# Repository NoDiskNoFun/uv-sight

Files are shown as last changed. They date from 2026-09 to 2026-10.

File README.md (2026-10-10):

# UV-Sight

Automatic UV illumination, cant indicator and shot counter for a compound bow hunting sight, with a companion web app.

> **Disclaimer: AI-generated project**
>
> The firmware, the web app, this README and the hardware design (part selection and wiring) were created with **Claude**, an AI assistant by Anthropic, in a conversation with the project owner.
>
> | | |
> |---|---|
> | Model | Claude Opus 5.5 (Anthropic) |
> | Interface | claude.ai, chat with code execution and web search |
> | Period | 23 September 2026, finished on 25 September 2026; reviewed and extended on 30 September 2026 |
> | Human role | Requirements and feature decisions, choice and purchase of parts, soldering and assembly, compiling and flashing, testing on the real bow, bug reports |
> | AI role | Part selection and wiring, all firmware and app code, protocol design, research of datasheets and pinouts, documentation |
> | Testing by the AI | Syntax and type checks of the firmware against mock libraries, JSON validity checks, and an end-to-end test of the app in Chromium against the firmware running natively with mocked IMU, flash and Bluetooth. The AI never ran the code on real hardware. |
> | Firmware / protocol / app | Firmware 5.8, protocol 16, app 5.11 |
>
> Several values in this project are estimates or were only checked in the field by the owner (runtimes, thresholds, shot detection). Treat them as starting points, not as guarantees. LiPo batteries can be dangerous if handled wrongly. Build and use this at your own risk.

---

## Contents

1. [Features](#features)
2. [Hardware](#hardware)
3. [Wiring](#wiring)
4. [Assembly and mounting](#assembly-and-mounting)
5. [Firmware: build and flash](#firmware-build-and-flash)
6. [Operation](#operation)
7. [Battery and charging](#battery-and-charging)
8. [Bluetooth commands](#bluetooth-commands)
9. [Settings reference](#settings-reference)
10. [Compile-time constants](#compile-time-constants)
11. [Web app](#web-app)
12. [JSON protocol (version 4)](#json-protocol-version-4)
13. [Troubleshooting](#troubleshooting)
14. [Known limitations](#known-limitations)

---

## Features

- **Automatic illumination:** The UV LED lights the sight's fluorescent fibre when it is dark and the bow is in use. Brightness is set in percent, either fixed or fading in with the dusk. It is held steady over the whole battery discharge via PWM.
- **Motion-based power management:** When the bow lies still, LED, light sensor and Bluetooth switch off, the accelerometer drops to 12.5 Hz and the board sleeps until the IMU reports motion on its interrupt line. Picking the bow up wakes it at once.
- **Cant indicator:** The LED blinks when the bow is canted sideways, faster the more it is tilted, or inverted: faster the closer to level. Aiming up or down does not count. Modes: off, auto (during a session) and on (always).
- **Shot counter:** Detects every shot through the impact on the riser (IMU tap detection via hardware interrupt). Shots are grouped into ends and training sessions.
- **Scoring:** Enter the scores of each end (0–10, X, M). Each end is checked against the counted shots. Sessions and their ends are stored on the board's 2 MB flash (room for about 32,000 records).
- **Battery:** USB-C charging at a fixed 50 mA, charge status, battery percentage and a deep-discharge cutoff for the LED.
- **Bluetooth:** Everything can be read and configured over Bluetooth LE (Nordic UART Service), either with a serial terminal app or with the included web app.
- **Web app (PWA):** Status, training keypad, history with chart, CSV export, backup and import, settings with guided calibration, automatic sync of sessions in both directions. Works offline once installed.
- **Aiming range (optional):** With the distance set per end, the sight learns which aiming angle belongs to which distance and can warn when the aim does not fit the distance. Several arrow/bow setups can be kept.
- **Update mode:** Reboot into the UF2 bootloader from the app, no double click on the reset button needed.

---

## Hardware

### Bill of materials

| # | Part | Type / value | Qty | Purpose |
|---|---|---|---|---|
| 1 | Microcontroller | Seeed Studio XIAO nRF52840 **Sense** | 1 | Control, Bluetooth, built-in LiPo charger (BQ25101), USB-C, 6-axis IMU (LSM6DS3TR-C) |
| 2 | LiPo battery | 3.7 V, 85 mAh, about 4 × 12 × 25 mm, with protection circuit | 1 | Power supply |
| 3 | UV LED | 5 mm, 390–405 nm (the owner reused the LED of the sight's original light, forward voltage measured 2.873 V at about 1 mA) | 1 | Lights the sight fibre, cant indicator |
| 4 | Resistor | 68 Ω, 1/4 W | 1 | LED current limit (about 16 mA peak at 4.2 V) |
| 5 | NPN transistor | BC547 (or BC337) | 1 | Switches the LED from the battery |
| 6 | Resistor | 2.2 kΩ, 1/4 W | 1 | Transistor base resistor |
| 7 | Photoresistor (LDR) | GL5528, 5 mm | 1 | Ambient light sensor |
| 8 | Resistor | 10 kΩ, 1/4 W | 1 | Voltage divider for the LDR |
| 9 | Wire | Thin flexible silicone wire, 2 cores, about 15–20 cm | 1 | Housing to LED in the sight |
| 10 | Heat shrink | Assorted sizes | – | Insulation, strain relief |
| 11 | Housing | Rigid, screwed to the riser | 1 | See [assembly](#assembly-and-mounting) |

No separate battery voltage divider, charger module or switch is needed: the XIAO board has a battery divider, charger and USB-C on board. Power management is done entirely in software.

### Why a transistor for the LED

A GPIO pin only delivers the regulated 3.3 V of the board. A UV LED needs about 3.0–3.4 V, which leaves nearly nothing for current regulation. The LED is therefore powered directly from the battery (3.4–4.2 V) and the GPIO only switches the transistor.

### Battery notes

- The battery used here has **three wires**. The third one is a temperature sensor (NTC). The XIAO has no pad for it: **cut it short and insulate it**, only plus and minus are connected.
- Use a cell with a built-in protection circuit. It is the last line of defence against deep discharge.

---

## Wiring

### Pin assignment

| Function | XIAO pin | nRF52840 | Notes |
|---|---|---|---|
| UV LED (PWM, via transistor) | D6 | P1.11 | Base of BC547 via 2.2 kΩ |
| LDR supply | D2 | P0.28 | Only HIGH during a measurement (saves power) |
| LDR measurement | D0 / A0 | P0.02 | Midpoint of the LDR divider |
| Battery voltage | internal | P0.31 | On-board divider 1 MΩ / 510 kΩ |
| Battery measurement enable | internal | P0.14 | Kept LOW permanently (must not be HIGH while charging) |
| Charge current select | internal | P0.13 | High-impedance input = 50 mA (set in code) |
| Charge status | internal | P0.17 | LOW = charging (board charge LED) |
| IMU interrupt INT1 | internal | P0.11 | Shot detection |
| IMU power | internal | P1.08 | Switched on by the firmware |

D1, D3–D5 and D7–D10 remain free.

### UV LED

```
BAT+ ---[68 Ω]--- LED anode (+, long leg) --- LED cathode (-, short leg) --- collector (C)
                                                                             BC547
D6 -----[2.2 kΩ]------------------------------------------------------------ base (B)

GND ------------------------------------------------------------------------ emitter (E)
```

BC547 pinout, flat side facing you, legs down: **C – B – E** from left to right. Check against the datasheet of your part.

### Light sensor

```
D2 ---[LDR GL5528]---+---[10 kΩ]--- GND
                     |
                     A0
```

The LDR has no polarity. Bright light means a high reading, darkness a low reading.

### Battery

```
Battery (+) --- BAT+ pad (bottom of the XIAO)
Battery (-) --- BAT- pad
Battery NTC (3rd wire) --- not connected, insulated
```

### Overview

```
                 +--------------------------------------+
   USB-C ------> |  XIAO nRF52840 Sense                 |
                 |   (charger, IMU, Bluetooth on board) |
                 |                                      |
   LiPo 85 mAh --| BAT+ / BAT-                          |
                 |                                      |
                 | D6 ---[2.2k]--- BC547 --- UV LED ----+---- to the sight (2-core wire)
                 | D2 ---[LDR]---+                      |
                 | A0 -----------+---[10k]--- GND       |
                 +--------------------------------------+
```

---

## Assembly and mounting

- **Mount the housing rigidly.** Shot detection relies on the impact travelling through the riser. Screw the housing on, ideally to an existing accessory thread. Foam double-sided tape and magnets dampen the impact and cause missed shots. Thin structural acrylic tape without a foam core is the fallback if screwing is impossible.
- **Orientation does not matter.** All three IMU axes are evaluated for shots, and the cant indicator is calibrated in place.
- **The LED sits in the sight,** the electronics in the housing, connected by thin silicone wire with strain relief. Mark the LED polarity before desoldering an original light.
- **Place the LDR so that no UV light from the sight falls on it,** otherwise the light could switch itself off.
- **Keep the transistor and the 68 Ω resistor in the housing,** not in the sight.

---

## Firmware: build and flash

### Setup (Arduino IDE)

1. Add this boards manager URL in the preferences:
   `https://files.seeedstudio.com/arduino/package_seeeduino_boards_index.json`
2. Install the board package **"Seeed nRF52 Boards"** (not the "mbed-enabled" variant).
3. Select the board **"Seeed XIAO nRF52840 Sense"**.
4. Install the library **"Seeed Arduino LSM6DS3"** via the library manager. Bluefruit and LittleFS are part of the board package.

### Setup (arduino-cli)

```sh
arduino-cli config add board_manager.additional_urls \
  https://files.seeedstudio.com/arduino/package_seeeduino_boards_index.json
arduino-cli core update-index
arduino-cli core install Seeeduino:nrf52
arduino-cli lib install "Seeed Arduino LSM6DS3"

arduino-cli compile --fqbn Seeeduino:nrf52:xiaonRF52840Sense path/to/uv_visier/
arduino-cli upload  --fqbn Seeeduino:nrf52:xiaonRF52840Sense -p /dev/ttyACM0 path/to/uv_visier/
```

The sketch file must have the same name as its folder, for example `uv_visier/uv_visier.ino`.

### Update mode (UF2)

Instead of double-clicking the reset button you can reboot the board into its UF2 bootloader:

- in the app: *Settings → Firmware and app → Update mode*, or
- in a terminal: send `dfu`.

The USB cable must be connected, otherwise the command is refused (the board would sit in the bootloader and drain the battery). The board appears as a USB drive. Copy a `.uf2` firmware onto it, or upload with the Arduino tools.

### What is stored in flash

| File | Where | Content | Saved |
|---|---|---|---|
| `/uvcfg.bin` | internal | Settings | With `save` |
| `/shotstate.bin` | internal | Shot counter on/off, log epoch, last session number | Automatically |
| `/level.bin` | internal | Cant indicator mode, calibration, LED switch, signals | Automatically |
| `/setups.bin` | internal | Arrow/bow setups | Automatically |
| `/sightname.txt` | internal | Name of this sight (`name <text>`) | Automatically |
| `/shotmodel.bin` | internal | Shot matching model per setup and its on/off switch | Automatically |
| `/bathist.bin` | internal | Battery history for the runtime estimate | Automatically |
| session log | external 2 MB QSPI flash | Sessions and ends as 64-byte records with CRC, ring buffer | Automatically |
| `/shots.old` | internal | Backup of the log format of firmware 1.2 to 2.1 after the migration | Once |

When a firmware update changes the layout of an internal file, that file starts over with defaults. The session log on the external flash keeps its format. Export a backup from the app before updating anyway.

---

## Operation

### Active and idle

- **Active:** The bow was moved within the timeout (default 5 min). LED logic, light sensor and Bluetooth run.
- **Idle:** The bow lies still. Everything is off. The IMU's interrupt line wakes the board when the bow moves; without motion it only wakes every 5 s for housekeeping. A Bluetooth connection is dropped when the board goes idle; a connection alone does not keep it awake. USB power or an `awake` hold from the app keep Bluetooth reachable without movement.
- A running session survives idle phases. It is only ended by `session_end` minutes without a shot, by `shots stop`, or by a restart of the board.

### Illumination

- Every 2 s the light sensor is read (0 = dark, 4095 = bright).
- `confirm` readings in a row are needed to switch. Right after picking up the bow the decision is immediate.
- **Brightness in percent** on a perceptual scale: 50 % looks about half as bright as 100 %. 100 % is 15 mA average, the former default of 5 mA is 61 %.
- **Fixed** (`bright_mode 0`): below `dark_on` the LED switches on with `bright`, above `dark_off` it switches off. The gap prevents flicker.
- **Auto** (`bright_mode 1`): getting darker, the LED comes on at `dark_off` with `bright_min` and gets brighter until it reaches `bright` at `dark_on`; below that it stays at `bright`. Getting brighter, it dims the same way and goes off above `dark_off`. The blend follows the light sensor logarithmically and glides over `fade` seconds instead of jumping.
- The brightness is kept steady by PWM (12 bit) as the battery voltage drops.
- Test modes: `mode on` (always on), `mode off` (always off), `mode auto` (normal). The mode is not saved.

### Cant indicator

| | level | canted |
|---|---|---|
| bright | LED off | LED blinks |
| dark | LED on | LED blinks |

- Blinking uses `bright` minus `tilt_offset` percentage points (0 = same brightness), independent of the current auto brightness.
- **Style normal:** just outside the tolerance `blink_min` (1 Hz), from `tilt_full` (10°) on `blink_max` (8 Hz), in between the rate rises linearly.
- **Style inverted** (`level style inverted`): just outside the tolerance `blink_max`, from `tilt_full` on `blink_min`, so fast blinking means you are close to level. Within the tolerance the LED behaves as in normal style (on when dark, off when bright).
- The cant reading is smoothed over `tilt_smooth` against hand tremor. Leaving the tolerance switches at `level_tol`, returning at 70 % of it, so the edge does not flicker.
- A new rate takes effect at the start of the next blink cycle.
- Only sideways cant counts. Aiming up or down is ignored thanks to the two-step calibration.
- After a shot the indicator pauses for `lockout` (default 1.5 s).

| Mode | Command | Behaviour |
|---|---|---|
| Off | `level off` | No blinking |
| Auto | `level auto` | Only during a running session (needs `shots on`) |
| On | `level on` | Always while the bow is active |

**Calibration (once, saved immediately):**

1. Put the bow in a stand, level it with the bubble and aim horizontally. Send `level cal`.
2. Keep the bow level, but aim clearly up or down, at least 20°. Send `level cal2`.

Each step waits 3 s, then measures for about 0.6 s. If the two positions differ by less than 15°, step 2 has to be repeated.

### Shot counter, sessions and ends

- Turn the counter on with `shots on` (saved immediately).
- **Session start:** automatically with the first detected shot, or manually with `shots start`.
- **Shot detection:** The IMU reports impacts above `tap_ths` via interrupt. After a shot further impacts are ignored for `lockout`. Setting the bow down at the end often counts as a shot; this is handled below.
- **Ends:** Each `score` line closes an end and is compared with the shots counted since the last entry.
  - Match: the end is saved.
  - Mismatch: the device asks `save anyway? (yes/no/split)`. `yes` saves your values and your arrow count wins over the sensor count. `split` (offered when fewer values than shots were entered) saves the values as one end and keeps the remaining shots for the next end. `no` discards the input and the end stays open. Any command that changes the session or a setting also discards the input; commands that only read (`status`, `log …`, `level`, …) and the sync commands of the app leave the question open.
  - `score skip` closes an end without scores: it is stored as invalid, the sensor's arrow count is used, all arrows count 0 points and are left out of the average.
- **Scores:** `0`–`10` and `x` (inner ten: 10 points, counted separately). Several values per line, for example `score x 10 9 9 8 7`. If one value is invalid, the whole line is rejected. The app shows 0 as M (miss).
- **Session end:** automatically after `session_end` minutes (default 60) without a shot, or with `shots stop`. An open last end with exactly 1 shot is ignored (bow set down); with more shots it is stored as invalid. Sessions without any end are discarded.
- **Stored per session:** ends, shots, scored arrows, average, X count, duration in minutes, invalid ends and arrows, flags (corrected by hand, ended by hand). There is no clock on the board; the app derives the date.
- The log lives on the external flash and holds about 32,000 records; the oldest are overwritten when it is full. The app can delete single sessions or the whole log on the sight.

---

## Shot matching

With the shot counter running, the sight also records how the bow moved at each release and tells the app, per shot, where it expects the arrow relative to the end's mean: the height from the aiming angle, the sideways position from the bow's rotation in the last 30 ms before the impact (gyroscope, read from the IMU FIFO, shot mode only). The app matches these predictions to the arrow positions it sees on the photo and reports the sure pairs back (`shot teach`). From them, each setup learns its own factors and the remaining spread, so the predictions and the app's confidence improve with every end. Everything is stored per setup in `/shotmodel.bin`; `shot model` shows the state, `shot reset` starts over, `shot off` turns matching and the gyro off. The gyro adds about 0.5 mA while the bow is active.

## Battery and charging

| Item | Value |
|---|---|
| Charge current | Fixed 50 mA (about 0.6 C for 85 mAh), about 2 h for a full charge |
| Charge termination | 4.2 V (charger chip) |
| LED cutoff | `cutoff`, default 3.40 V; released again at cutoff + 0.25 V |
| Percentage | 0 % = `cutoff`, 100 % = 4.2 V, following a typical LiPo curve |
| Charge status | `charging`, `full` (USB connected, done), `no USB` |

- While charging the voltage reads higher than at rest, so the percentage is optimistic. After charging a full cell settles to about 4.10–4.15 V.
- The ADC uses a 40 µs acquisition time because the on-board battery divider has a very high impedance. With the default 3 µs the voltage read about 0.1 V too low.
- The microcontroller keeps running below the cutoff; the battery's own protection circuit disconnects at roughly 2.5–3.0 V. The cutoff is what protects the cell from the LED.

### Runtime estimates

These are estimates, not measurements.

| Mode | Current (approx.) | Runtime with 85 mAh |
|---|---|---|
| Idle (bow lies still) | 0.04–0.08 mA | several weeks up to about 2 months |
| Active at night, LED at 61 % (5 mA) | about 6 mA | about 14 h |
| Active in daylight, training, no LED | 0.5–1 mA | several days |

Measurements taken with a USB power meter are not meaningful for battery runtime: with USB connected, the USB interface of the chip is active and the LED draws from the battery, not from USB.

---

## Bluetooth commands

Connect with any Nordic UART terminal (for example the Android app "Serial Bluetooth Terminal", line ending LF or CR+LF), with `ble-serial` on Linux, or with the web app. The board advertises as **UV-Sight** only while it is active.

| Command | Effect | Saved |
|---|---|---|
| `help` or `h` | List of commands | – |
| `status` or `?` | Current readings | – |
| `get` or `config` | All settings with range | – |
| `set <name> <value>` | Change a setting, active immediately | Only with `save` |
| `save` | Save settings to flash | Yes |
| `defaults` | Load default settings | Only with `save` |
| `live on` / `live off` | Status every 2 s | No |
| `mode auto` / `on` / `off` | LED test mode | No |
| `shots` | Counter status and running session | – |
| `shots on` / `shots off` | Shot counter on/off (off only without a running session) | Immediately |
| `shots start` / `shots stop` | Start / end a session manually | Slot on end |
| `score 9 x 7 0` | Score an end | With the session |
| `score skip` | Close the end without scores (invalid) | With the session |
| `yes` / `no` | Answer a mismatch question | – |
| `log` | Stored sessions, 1 = newest | – |
| `level` | Cant indicator status | – |
| `level off` / `auto` / `on` | Cant indicator mode | Immediately |
| `level style normal` / `inverted` | Blink faster when tilted / when close to level | Immediately |
| `level cal` / `level cal2` | Calibration step 1 / 2 | After step 2 |
| `level signal on` / `off` | Blink when canted (measuring continues) | Immediately |
| `angle off` / `auto` / `on` | Measure the aiming angle at every shot | Immediately |
| `dist <m>` | Distance of the running session (0 = unknown); `score … @50` also sets it | With the session |
| `range`, `range signal on` / `off` | Learned distances and arrow speed; warning when the aim does not fit | Immediately |
| `setup`, `setup use` / `new` / `name` / `del` | Arrow/bow setups, each learns its own speed | Immediately |
| `log all`, `log since <n>`, `log ends <e> <id>`, `log info`, `log test` | Whole log, records after #n, ends of a session, flash status, flash self-test | – |
| `log put …`, `log putend …` | Write a session / end from a backup (used by the app) | Yes |
| `log del <e> <id>`, `log clear confirm` | Delete one session / all sessions on the sight | Yes |
| `bat`, `bat reset` | Runtime estimate and measured current draw; clear the battery history | – / Yes |
| `time <unix> [tz]` | Set the clock (the app does this on every connect) | Until reboot |
| `awake <s>` | Stay reachable without movement, max 900 s | No |
| `app on` / `app off` | JSON output for the app / human-readable output | No (off on disconnect) |
| `name [text]`, `name -` | Name this sight (max. 16 characters); it appears in the app and behind "UV-Sight" in the Bluetooth name. `-` removes the name. The app also receives a fixed chip id, so two sights are told apart even without a name | Yes |
| `shot list [m]` | Shots of the open end, one line each (`shotsStart`, `shotItem`…, `shotsEnd`): time, aiming angle, hold spread and duration, sinking before release, cant, bow rotation at release and the model's predicted position. The same lines follow every closed end | – |
| `shot trace [last] <i>` | Aim trace of one shot: angle and cant over the 1.9 s before the release | – |
| `shot teach <end> <i>:<dx>:<dy> …` | Confirmed arrow positions (mm from the group's mean) for shots of the last closed end: the model learns from them | Yes |
| `shot model`, `shot reset [id]`, `shot on`/`shot off` | Shot matching model of the active setup: state, reset, switch (off also turns the gyro off) | Yes |
| `dfu` | Reboot into update mode (USB needed) | – |

Range is about 10 m at the default `tx_power` of 0 dBm; +8 dBm roughly doubles it. A cheap USB adapter without antenna, a metal PC case or a nearby USB 3 port can reduce the range a lot. Anyone within range can connect; there is no PIN.

---

## Settings reference

Change with `set <name> <value>`, keep with `save`. Out-of-range values are rejected. Settings saved by firmware before 1.8 in mA (`ma`, `tilt_ma`) are converted to percent automatically on the first start.

| Name | Meaning | Unit | Default | Min | Max |
|---|---|---|---|---|---|
| `dark_on` | Fixed: light on below. Auto: full brightness from here down | 0–4095 | 900 | 0 | 4095 |
| `dark_off` | Fixed: light off above. Auto: light starts here with `bright_min` | 0–4095 | 1200 | 0 | 4095 |
| `confirm` | Consecutive readings (2 s each) before switching | count | 2 | 1 | 10 |
| `bright_mode` | 0 = fixed, 1 = auto (fades with the light sensor) | – | 0 | 0 | 1 |
| `bright` | Brightness (fixed), or at `dark_on` and darker (auto) | % | 61 | 1 | 100 |
| `bright_min` | Auto: brightness at `dark_off`, where the light starts | % | 25 | 1 | 100 |
| `tilt_offset` | Cant blinking: percentage points below `bright` | % | 32 | 0 | 99 |
| `fade` | Auto: time to follow a change in darkness, 0 = instant | s | 5 | 0 | 30 |
| `tilt_full` | Cant at which the blink rate reaches its end value | degrees | 10.0 | 1 | 30 |
| `blink_min` | Slow blink rate (normal: just outside the tolerance) | Hz | 1.0 | 0.5 | 12 |
| `blink_max` | Fast blink rate (normal: from `tilt_full` on); above ~10 Hz it looks steady | Hz | 8.0 | 0.5 | 12 |
| `tilt_smooth` | Smoothing of the cant reading against hand tremor | ms | 400 | 50 | 2000 |
| `session_end` | Minutes without a shot until the session ends | min | 60 | 5 | 480 |
| `vf` | Forward voltage of the UV LED (for the brightness control) | V | 3.00 | 2.50 | 3.60 |
| `cutoff` | Battery cutoff for the LED, equals 0 % | V | 3.40 | 3.00 | 3.70 |
| `level_tol` | Cant tolerance | degrees | 1.0 | 0.2 | 10 |
| `tap_ths` | Shot threshold | × 0.25 g | 20 (5 g) | 1 | 31 |
| `ths` | Wake-up motion threshold | × 125 mg | 1 | 1 | 63 |
| `lockout` | After a shot: no counting, cant indicator paused | ms | 1500 | 200 | 5000 |
| `timeout` | Time without movement until idle | s | 300 | 10 | 3600 |
| `report` | Automatic status while connected, 0 = off. A status the app asks for restarts this timer, so polling and reports do not double up | s | 10 | 0 or 2 | 600 |
| `tx_power` | Bluetooth transmit power, rounded to −20, −16, −12, −8, −4, 0, 2…8 | dBm | 0 | −20 | 8 |
| `bat_mah` | Battery capacity, for the runtime estimate | mAh | 85 | 10 | 5000 |

**Calibrating the light thresholds:** at dusk send `live on`, watch the `Light=` value, set `dark_on` where the fibre no longer glows by itself and `dark_off` about 300 higher. Then `live off` and `save`.

**Calibrating the shot threshold:** every detected shot is reported. Shoot a few arrows and carry the bow around. Lower `tap_ths` if shots are missed, raise it if carrying counts as a shot. Then `save`.

---

## Compile-time constants

`UV_HAS_LED` (default 2): whether the UV LED stage (BC547, resistors, LED, light sensor) is fitted. 0 = no, for a sight on a bow without a pin, e.g. a hunting bow, that only counts shots and measures angles; 1 = yes; 2 = find out at boot. The check charges the LED pin and lets it float for a moment: with the transistor and its base resistor fitted the pin falls to the base-emitter voltage, without them it stays high. Without the LED stage the light settings default to off, the light sensor is not read, `mode on`, `level signal on` and `range signal on` are refused, and the app hides all light options (the `hello` message carries `"led":false`). Set it on the command line with `--build-property compiler.cpp.extra_flags=-DUV_HAS_LED=0`.

These are set at the top of the sketch and need a rebuild.

| Constant | Value | Meaning |
|---|---|---|
| `BRIGHT_MAX_MA` | 15 mA | LED current at 100 % |
| `BRIGHT_GAMMA` | 2.2 | Perceptual curve from percent to current |
| `PWM_BITS` | 12 | PWM resolution for fine steps at low brightness |
| `MAX_SCORES_LINE` | 40 | Maximum values per `score` line |
| `TILT_HYST_FRAC` | 0.3 | Hysteresis at the tolerance edge as a share of `level_tol` |
| `CAL_MIN_ANGLE_DEG` | 15° | Minimum angle between the calibration steps |
| `CAL_COUNTDOWN_MS` | 3000 ms | Wait before a calibration measurement |
| `SENSOR_INTERVAL_MS` | 2000 ms | Light and battery reading interval |
| `ACTIVE_POLL_MS` / `LEVEL_LOOP_MS` | 250 / 30 ms | Loop interval active / with cant indicator or aiming angle |
| `IDLE_WAKE_MAX_MS` / `IDLE_POLL_MS` | 5000 / 500 ms | Idle: longest sleep between housekeeping passes (the IMU interrupt ends it earlier) / poll interval if the board package has no INT1 pin |
| `TWIM_ANOMALY_89` | 1 | nRF52840 erratum 89 workaround (I2C peripheral off between loop passes): 0 = never, 1 = automatic (the firmware asks the Nordic MDK whether the chip revision is affected; only Engineering A is), 2 = always. `bat` shows whether it is active |
| `ADV_FAST_INTERVAL` / `ADV_SLOW_INTERVAL` | 100 ms / ~1 s | Advertising for the first 10 s / afterwards |
| `CONN_INT_MIN` / `CONN_INT_MAX` | 200 / 400 ms | Requested connection interval |
| `BLE_NAME` | `UV-Sight` | Bluetooth name |

---

## Web app

### Files

All six files belong in one folder:

```
index.html
sw.js
manifest.webmanifest
icon-192.png
icon-512.png
icon-maskable-512.png
```

The main file must be named exactly `index.html`.

### Hosting and installing

Web Bluetooth only works in **Chrome** and only on pages loaded via **https** or **localhost**. Opening the file directly from storage does not work.

- **Online Version**: [https://nodisknofun.github.io/uv-sight/](https://nodisknofun.github.io/uv-sight/)
- **Local server on the phone:** serve the folder with a local web server app and open `http://localhost:8080/`.
- **GitHub Pages:** create a repository, upload the six files, enable *Settings → Pages* for the `main` branch. The app is then at `https://<user>.github.io/<repo>/`.
- **Own server:** any static https web server.

Open the app once completely, then install it via *Settings → Install app* or the Chrome menu. After that it starts from the home screen without internet. When the server is reachable it loads updates automatically (network first, cached copy after 2.5 s).

If the device chooser stays empty, give Chrome the permission *Nearby devices* (Android 12 and later) or *Location* (older Android).

### Tabs

- **Status:** battery ring with percentage and voltage, session, UV light with brightness and mode (fixed/auto), ambient light, cant with mode and style, charging, and runtime estimates with light and resting. Refreshes every 5 s while open.
- **Runtime estimate:** remaining capacity (battery capacity × percentage) divided by an estimated current: LED at `bright` plus about 0.6 mA for the awake board, 0.2 mA each for shot detection and the cant indicator when switched on; resting about 0.06 mA. In auto mode the estimate assumes full brightness. Set the battery capacity under *Settings → Firmware and app* (default 85 mAh, stored on the phone).
- **Training:** current end with live shot count, session statistics, keypad in target ring colours (`1 2 3 / 4 5 6 / 7 8 9 / 10 X M`, undo), save end, skip end, end session. Scoring works without a connection; Save, Skip and End reconnect automatically (up to 10 s) and keep your entries if the sight is out of range. Entries survive an app restart. Mismatch questions appear as a dialog; *Edit scores* keeps your entries for correction.
- **History:** sessions from the device are archived on the phone without duplicates, with date, chart of the average and CSV export. Removing an entry only affects the phone.
- **Dates:** the sight has no clock. The app takes the date from the phone: when a session ends while connected, from `ago` when fetched later, or from the start time it remembered while it saw the session running. Only if the app was never connected during a session and the sight restarted before the session was fetched, the list shows "Before <fetch time>".
- **Settings:** battery capacity for the estimate, shot counter, cant indicator (off/auto/on) and blink style (normal/inverted), LED test, brightness mode (fixed/auto), all settings grouped with slider, number field, description, default and range, save bar, restore defaults, guided cant calibration, update mode, install button, versions.
- **Console:** raw lines and free command input for troubleshooting.

The archive is stored in Chrome's site data. Clearing Chrome's site data deletes it; export CSV now and then as a backup.

---

## JSON protocol (version 16)

After `app on` the device sends **only JSON, one object per line**, until `app off` or disconnect. Commands stay the same text commands. Every object has a type field `t`. Lines that do not start with `{` (for example the greeting before `app on`) can be ignored.

On `app on` the device sends `hello`, the settings (`cfgStart`, `cfgItem` …, `cfgEnd`), `status`, `session`, `level`, `loginfo`, `range` and the setups (`setupsStart`, `setupItem` …, `setupsEnd`).

| Type | Fields | Sent |
|---|---|---|
| `hello` | `proto`, `fw`, `name`, `imu`, `log` | On `app on` |
| `status` | `light`, `dark`, `vbat`, `pct`, `chg` (`charging`/`full`/`no USB`), `led` (`on`/`off`/`blinking`/`warning`/`pulsing`), `duty` (0–4095), `bright` (%), `mode`, `lowbat`, `tilt` (degrees or `null`), `session`, `awake`, `rwarn`, `lastShotG`, `lastShotClip`, `end`, `endShots` | On `status`, with `live on` every 2 s, every `report` s |
| `bat` | `light`, `rest` (hours), `full` (minutes or `null`), `src` (`measured`/`estimate`), `idleMa`, `activeMa`, `ledK`, `cap` | With every status |
| `cfgStart` | `n` | Start of the settings list |
| `cfgItem` | `k`, `v`, `def`, `min`, `max`, `dec`, `zero`, `unit`, `d` | One per setting |
| `cfgEnd` | – | End of the settings list |
| `session` | `counter`, `active`; if active also `epoch`, `nextId`, `dist`, `distSrc`, `end`, `endShots`, `ends`, `invalidEnds`, `shots`, `scored`, `sum`, `x`, `avg`, `min`, `pending` | On `shots`, after every change |
| `shot` | `end`, `endShots`, `total`, `g`, `clip`, `ang`, `cant` | Every detected shot |
| `end` | `n`, `valid`, `arrows`, `dist`, `distSrc`, `setup`, `ang`, `angSd`, `angN`, `cant`, `cantMax`, `canted`, `cantN`, `stored`; valid: `sum`, `x`, `avg`; invalid: `reason` | An end was closed |
| `confirm` | `end`, `counted`, `entered`, `split` | Mismatch, answer with `yes`, `no` or `split` |
| `discarded` | `end` | Input discarded, end still open |
| `sessionEnd` | `manual`, `stored`, `epoch`, `id`, `seq` (0 if not stored), `error` | Session ended (`stored:false` for empty sessions or a flash error); a `slot` line with the details follows |
| `logStart` | `since`, `last`, `total`, `epoch` | Start of a log answer |
| `slot` | `seq`, `epoch`, `id`, `start`, `ago`, `ends`, `shots`, `scored`, `avg`, `x`, `min`, `invalidEnds`, `invalidArrows`, `mismatch`, `manual` | One per stored session |
| `endrec` | `seq`, `epoch`, `id`, `n`, `valid`, `arrows`, `skipped`, `sum`, `x`, `dist`, `auto`, `setup`, `ang`, `angSd`, `angN`, `cant`, `cantMax`, `canted`, `cantN`, `scores` | One per stored end |
| `logEnd` | `last`, `n` (records sent in this answer) | End of a log answer. The app compares `n` with what it received and asks again if a line was lost |
| `loginfo` | `ok`, `jedec`, `count`, `capacity`, `last`, `clock`, `migrated`, `error`, `initErr`, `resets` | On `log info` and `app on` |
| `range` | `setup`, `name`, `state` (`learning`/`anchor`/`ready`), `ends`, `dists`, `min`, `max`, `speed`, `kmh`, `drag`, `dist`, `distSrc`, `estimated`, `signal`, `warn`, `ok` | On `range`, after changes |
| `setupsStart` / `setupItem` / `setupsEnd` | `active`; per item `id`, `name`, `deleted`, `state`, `ends`, `kmh`, `min`, `max` | On `setup`, after changes |
| `logtest` | `step`, `ok`, `detail` | During `log test` |
| `level` | `mode` (`off`/`auto`/`on`), `style` (`normal`/`inverted`), `cal`, `angle` (`off`/`auto`/`on`), `cantSignal`, `rangeSignal` | On `level`, after changes |
| `cal` | `step`, `state` (`countdown`/`ok`/`error`), `text` | During calibration |
| `event` | `e`: `idle`, `lowbat`, `charge` (+`state`), `light` (+`dark`), `range` (+`warn`: `low`/`high`/empty, `ok`) | Device events. `range` is sent whenever the aiming-range signal changes, so an app can mirror the LED (e.g. by vibrating) |
| `ack` | `cmd`: `set` (+`k`, `v`), `save`, `live` (+`on`), `mode` (+`mode`), `dfu`, `dist`, `awake`, `time`, `batreset`, `setup` (+`ok`, `id`), `put` / `putend` (+`result`), `del` (+`result`), `clear` (+`ok`, `count`) | Confirmation of a command |
| `err` | `text` | Error |
| `msg` | `text` | Any other human-readable message |

**Session identity:** `epoch` is a random number of the log, newly created whenever the log starts empty. `id` is a running session number. `epoch` + `id` identify a session uniquely. A running session already reports the key it will get (`epoch` + `nextId`). `seq` is the write number of a record on the flash; the app remembers the newest `seq` it has and asks for `log since <seq>`. `start` is the unix time of the session start if the app had set the clock, `ago` the number of minutes since the session was saved, or `null` after a reboot of the board.

**Why short lines:** long lines (about 1,500 characters) were lost or corrupted over Bluetooth in practice. The settings are therefore sent as one short line per item. No line is longer than about 350 characters.

---

## Troubleshooting

| Problem | Cause and fix |
|---|---|
| App or terminal does not find `UV-Sight` | The board is idle. Move the bow, then search within 10 s. |
| PC finds the sight only briefly or not at all | Weak adapter: use a USB extension cable, avoid USB 3 ports, or raise `tx_power`. On Linux connect directly with `ble-serial -d <MAC> -t 15`; pairing is not needed. |
| Connection drops | After `timeout` without movement the board disconnects on purpose. Move the bow or raise `timeout`. |
| Settings tab says "Loading settings…" for long | Lines got lost. The app retries three times; move closer and tap *Try again*. |
| Protocol warning in the app | Firmware and app versions do not match. Update both. |
| Status reports keep coming after `live off` | That is the periodic `report`. Set `report 0` to switch it off. |
| Linker error about `GPIOTE_IRQHandler` | The sketch owns the GPIOTE interrupt for the IMU line. Nothing else in the sketch may call `attachInterrupt`. |
| LED switches nervously at dusk | Raise `confirm` or widen the gap between `dark_on` and `dark_off`. |
| Fibre too bright in full darkness | Lower `bright`; in auto mode it applies from `dark_on` down. |
| Shots are not counted | Check `shots` is on and the housing is screwed rigidly. Lower `tap_ths`. |
| Carrying the bow counts as a shot | Raise `tap_ths`. Setting the bow down at the end of a session is handled automatically. |
| Cant indicator never blinks | Check `level`: mode, calibration, and in auto mode a running session. |
| Cant blinks although the bubble is centred | Repeat the calibration or raise `level_tol`. |
| Battery percentage too high while charging | Normal, read it some minutes after unplugging. |
| LED stays off, "BATTERY EMPTY" | Deep-discharge protection. Charge the battery. |
| Settings lost after restart | `save` was missing, or the settings layout changed with a firmware update. |
| Compile error "does not name a type" | Arduino generates function prototypes before the first function; all types must be defined above it. Keep the order of the sketch. |
| Warning "PIN_LSM6DS3TR_C_INT1 not defined" | Board package without the interrupt pin; shot detection falls back to polling and may miss shots. |

---

## Known limitations

- **No clock:** sessions have no timestamp on the device. Dates come from the phone and are only approximate ("Before …") if the app never saw the session running and the sight restarted before it was fetched.
- **Shot detection by impact threshold:** setting the bow down hard can count as a shot. The threshold has to be tuned per bow and mounting position.
- **No Bluetooth security:** anyone in range can connect and change settings while the bow is active.
- **Cold:** below 0 °C LiPo capacity drops noticeably; runtime will be shorter than estimated.
- **Estimates:** runtimes and some thresholds are estimates and were not measured by the author of the code.
- **Web Bluetooth:** only Chrome on Android is supported; iPhone browsers do not support Web Bluetooth.
- **Erratum 89 of the chip:** the nRF52840 erratum that adds up to about 0.4 mA while the I2C peripheral stays enabled next to GPIOTE only affects the revision Engineering A, which no XIAO board carries. The firmware checks the revision at start and applies the workaround only there (`TWIM_ANOMALY_89`).

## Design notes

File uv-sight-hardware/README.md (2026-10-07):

# UV-Sight Hardware

Carrier board and 3D-printed case for **UV-Sight**: automatic UV illumination, cant indicator and shot counter for a compound bow sight, built around a Seeed Studio XIAO nRF52840 Sense.

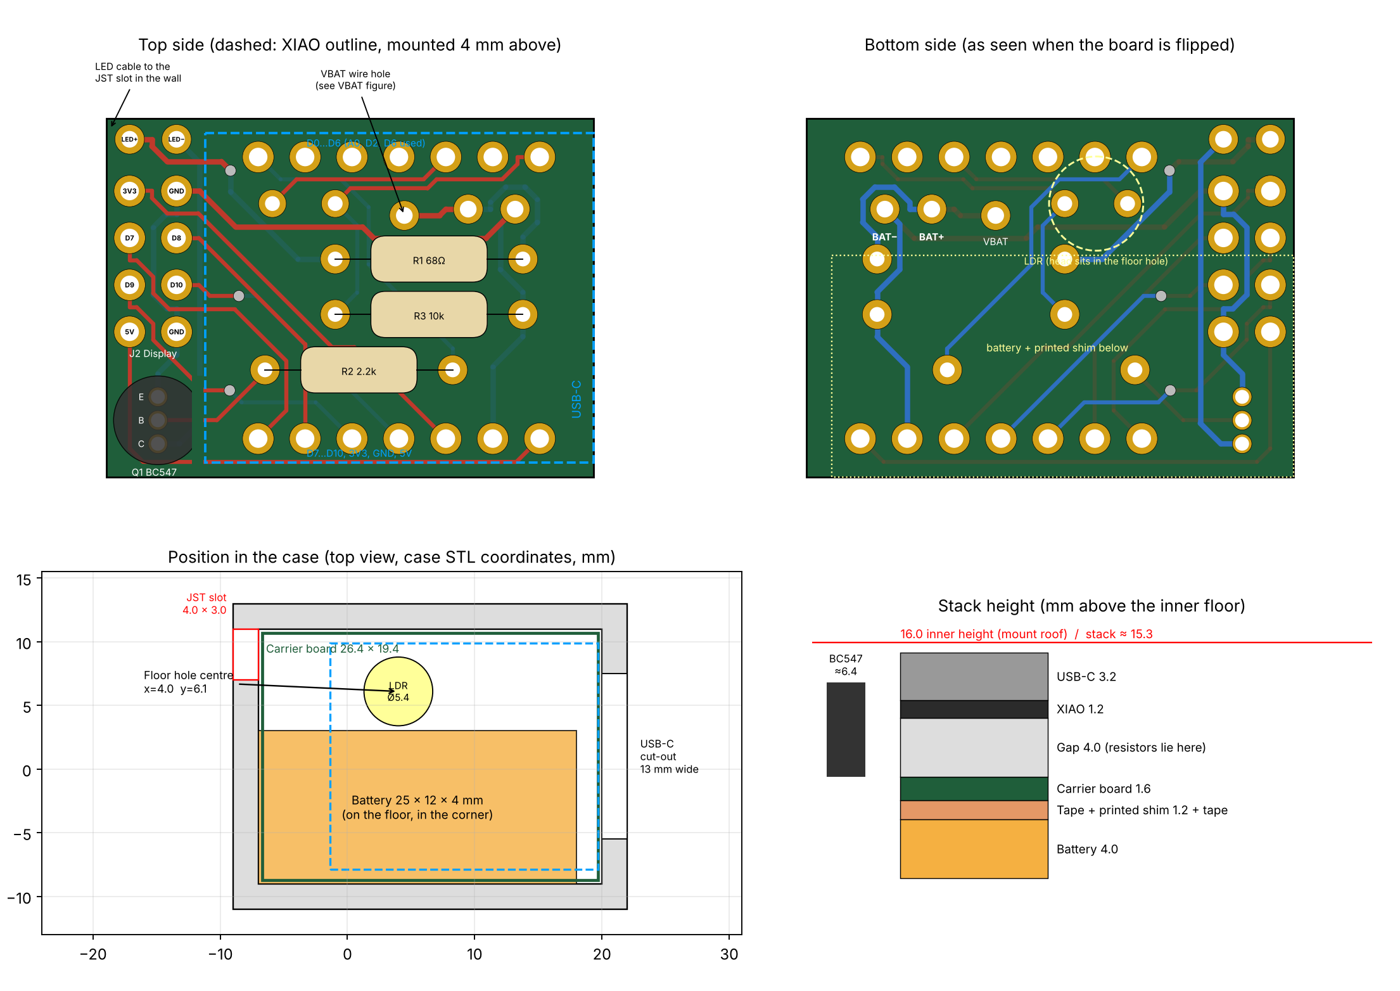
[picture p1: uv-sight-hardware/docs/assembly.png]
Assembly overview


> **AI-generated design.** The board layout, schematic, case modifications and this guide were created with Claude (Anthropic) together with the project owner. The design has been checked with KiCad's design rule check and against the 3D models, but **it has not been built and tested on real hardware yet.** Build at your own risk. LiPo batteries can be dangerous if handled wrongly.

---

## What's in this folder

| Folder / file | What it is | Do you need it? |
|---|---|---|
| `gerber/uv-sight-carrier_gerber.zip` | Manufacturing files for the board | **Yes**: upload this zip to a PCB maker |
| `3d-print/case.stl` | Case, fits the bow mount | **Yes**: print it |
| `3d-print/shim.stl` | 1.2 mm spacer between battery and board | **Yes**: print it |
| `3d-print/header-spacer.stl` | 1.5 mm strip that lifts the XIAO on its pin header | **Yes**: print it **twice** |
| `3d-print/rail-test/` | Four short test pieces to find the right rail fit for your printer | Recommended |
| `docs/` | Assembly drawing, VBAT wire drawing, schematic (PDF), mount fit | Read while building |
| `kicad/` | KiCad project (schematic and board) | Only if you want to change the design |

---

## 1. Order the board

Upload `gerber/uv-sight-carrier_gerber.zip` to any PCB maker (JLCPCB, PCBWay, Aisler and others). Use these settings:

| Setting | Value |
|---|---|
| Layers | 2 |
| Size | 26.4 × 19.4 mm |
| Thickness | **1.6 mm** (the height of the case is calculated with 1.6 mm) |
| Surface finish | HASL lead-free or ENIG |
| Colour | any |

Minimum track width 0.3 mm, minimum clearance 0.2 mm and minimum drill 0.3 mm are standard at every maker.

## 2. Print the parts

**Material: PETG** (or ASA if your printer has an enclosure). Do not use PLA. It softens at about 55 °C, for example in a car in summer, and becomes brittle in the cold.

- Use an **opaque, dark** filament. Translucent plastic lets light through the walls onto the light sensor and spoils the light reading.
- Layer height 0.12–0.16 mm, at least 5 perimeters (the 2 mm walls come out solid).
- Print the case with the open side up.

**Rail fit:** the rails on the sides of the case slide into the bow mount. Printers differ, so first print the four pieces in `3d-print/rail-test/`, **in the same material as the case**. They have 0.10, 0.15, 0.20 and 0.25 mm less material on each face of the rail. The number of notches on top of one wall tells you which is which (1 notch = 0.10 mm, 4 notches = 0.25 mm). Pick the one that slides in with a little force. `case.stl` uses **0.15 mm**. If you need another value, the case has to be regenerated with that value.

## 3. Parts list

| Ref | Part | Qty | Notes |
|---|---|---|---|
| U1 | Seeed Studio XIAO nRF52840 **Sense** | 1 | |
| – | Pin header 1×7, 2.54 mm | 2 | connects the XIAO to the carrier board |
| – | `header-spacer.stl`, printed | 2 | lift the XIAO to 4 mm above the board so the resistors fit underneath |
| R1 | Resistor 68 Ω, 1/4 W | 1 | LED current |
| R2 | Resistor 2.2 kΩ, 1/4 W | 1 | transistor base |
| R3 | Resistor 10 kΩ, 1/4 W | 1 | light sensor divider |
| Q1 | BC547 (or BC337), TO-92 | 1 | |
| R4 | Photoresistor GL5528, 5 mm, leaded | 1 | |
| J1 | LiPo 3.7 V, 85 mAh, about 4 × 12 × 25 mm, **with protection circuit** | 1 | wires soldered to J1 |
| J3 | UV LED 5 mm, 390–405 nm, on a 2-wire cable | 1 | sits in the sight |
| – | Micro-JST 1.25 mm 2-pin plug + socket with wires (PicoBlade compatible, about 4 × 3 mm) | 1 pair | LED cable through the case wall |
| – | Thin insulated wire, e.g. 30 AWG wire-wrap wire | ~2 cm | **VBAT wire** (see step 6) |
| – | Double-sided tape without foam core, e.g. 3M 467MP | – | holds battery, shim and board |
| – | Pin header 2×4 or wires (optional) | 1 | display connector J2 |

## 4. Build the board

The order matters: the XIAO covers everything below it once it is soldered in.

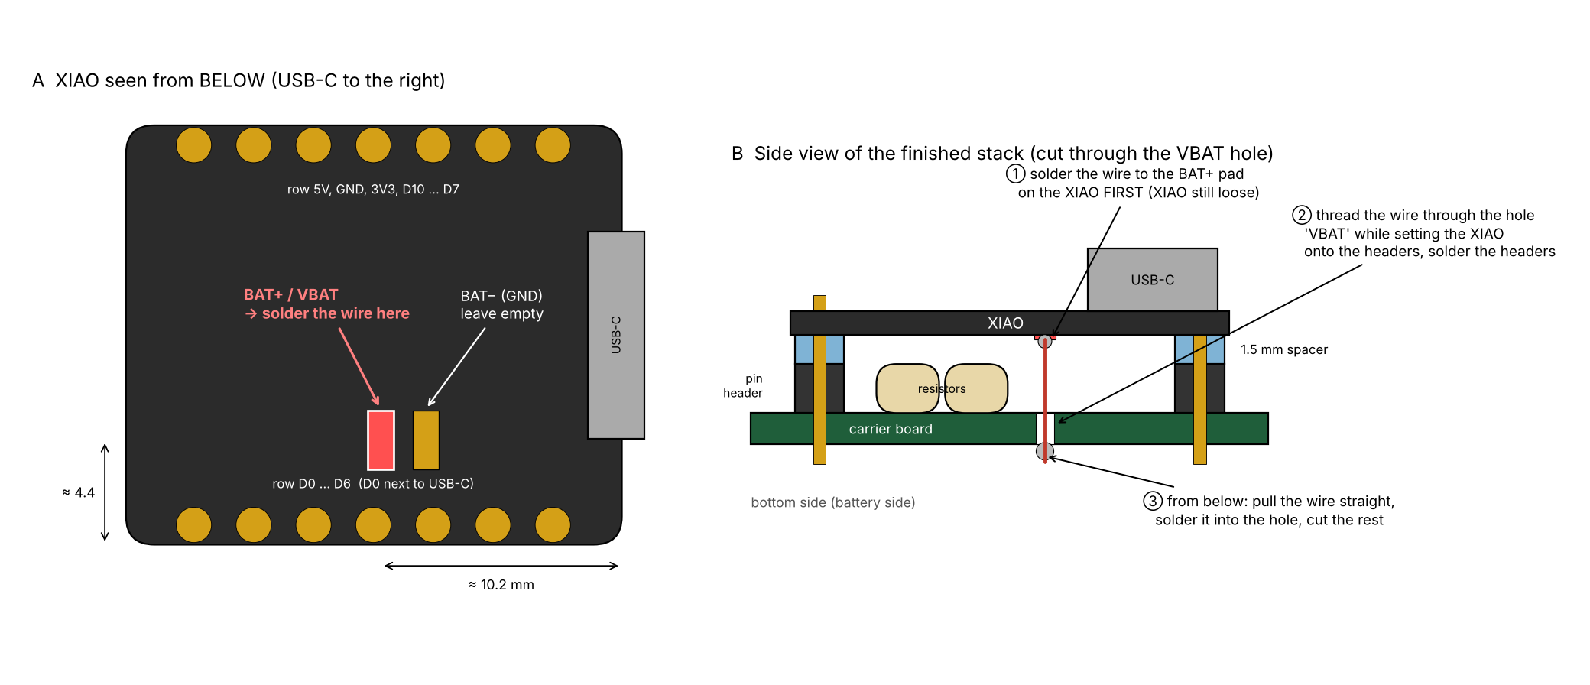
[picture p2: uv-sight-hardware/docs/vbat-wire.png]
VBAT wire


1. **Resistors R1, R2, R3.** Insert them from the top, lying flat; the values are printed on the board. Solder them on the bottom and cut the leads short.
2. **Light sensor R4 (LDR).** Insert it **from the bottom**, so its head is on the battery side, and solder it on the top. **Keep the legs long**: the head has to reach down into the hole in the case floor, about 6 mm below the board. Bend it to height later in the case.
3. **Transistor Q1.** Insert it from the top, standing, **flat side facing the XIAO**. The collector goes into the square pad. Solder it on the bottom.
4. **Battery wires (J1).** Insert them from the bottom and solder them on the top. **BAT+ goes into the square pad.** The battery's third wire (temperature sensor) is not used: cut it short and insulate it.
5. **LED cable (J3).** Use the JST pigtail. Insert it from the top and solder it on the bottom. **LED+ (anode, long LED leg) goes into the square pad.** Leave some slack inside the case and tie a knot in the cable as strain relief.
6. **VBAT wire.** This is the only tricky step; see the drawing above.
   - **Why it is needed:** the XIAO takes battery power only from a small **BAT+** pad on its **underside**, not from a header pin. The LED also needs battery voltage, so a short wire brings BAT+ from that pad down to the carrier board, into the hole marked **VBAT**.
   - **a)** Turn the bare XIAO upside down. Find the two pads in the middle: **BAT+** is about 10 mm from the USB-C end and about 4.4 mm from the D0–D6 edge. Solder about 15 mm of thin insulated wire to it, pointing straight away from the board. Leave the BAT− pad next to it empty: it is ground and is already connected through the GND header pin.
   - **b)** Put both 1×7 pin headers into the carrier board, long pins up, and slide a printed `header-spacer` over the pins of each header, on top of the black plastic. Set the XIAO onto the pins with USB-C at the end **opposite** J2, and **thread the wire through the VBAT hole** as you do. Solder the XIAO to the pins on top, then the pins on the bottom.
   - **c)** From the bottom, pull the wire straight, solder it into the VBAT hole and cut off the rest.
7. **Bottom side.** Cut all lead ends as short as possible with flush cutters.
8. **Check before connecting anything:** with a multimeter, make sure there is **no short between BAT+ and BAT−** on J1, and that the VBAT hole is connected to BAT+.

## 5. Put it into the case

1. **Battery:** stick it flat onto the case floor with tape, in the corner away from the hole in the floor.
2. **Shim:** tape `shim.stl` onto the battery. The solder joints on the bottom of the board sit in the cut-outs of the shim. **Never let solder joints touch the LiPo**: a sharp lead can pierce the pouch and short the cell.
3. **Board:** tape the board onto the shim, USB-C towards the wide cut-out. Bend the LDR so that its head sits in the floor hole.
4. **JST connector:** press it into the slot at the top of the end wall opposite USB-C. The slot is made to the plug's measured size of 4.0 × 3.0 mm; file it if it is too tight. Fix it from inside with a little hot glue.

**Never solder on the board while the battery is attached underneath.**

The stack is about 15.3 mm high, and the case is 16 mm high inside.

## 6. Bow mount

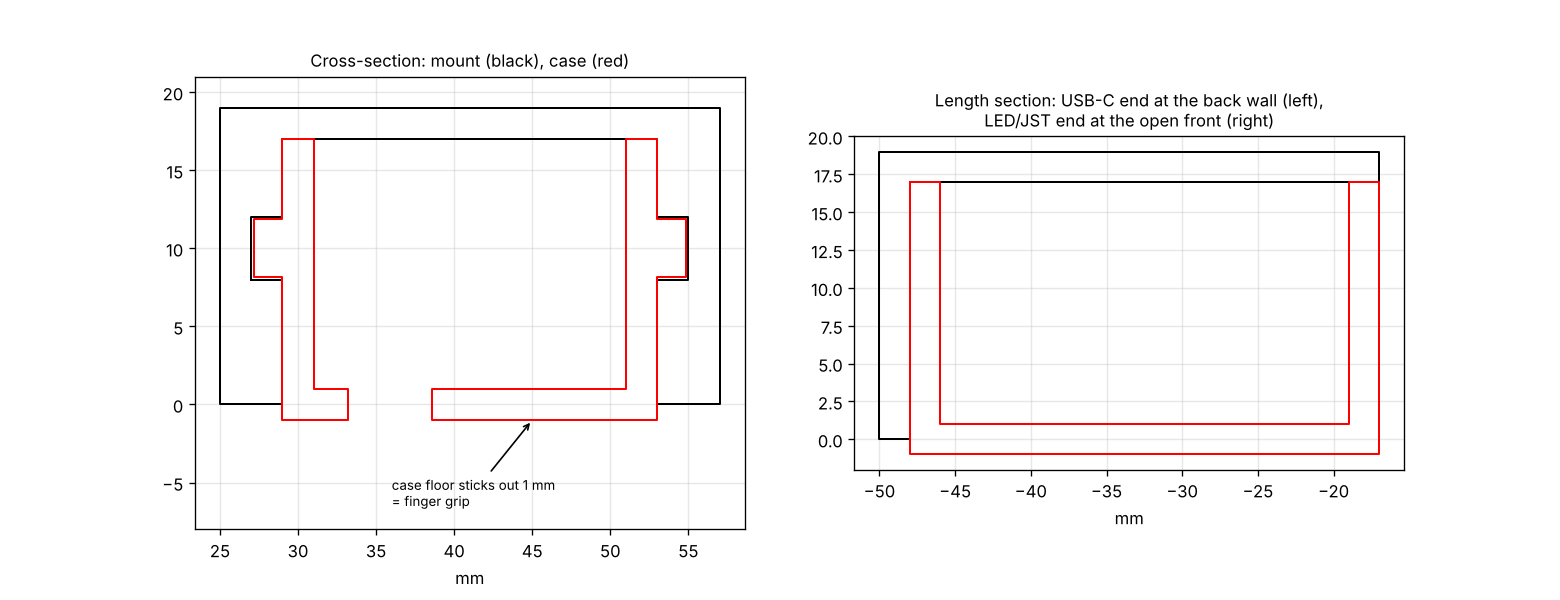
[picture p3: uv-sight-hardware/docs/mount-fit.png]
Mount fit


The mount has a closed roof (it closes the open top of the case) and a closed back wall. Slide the case in **USB-C end first**, so that the **LED/JST end faces the open front**. The case floor sticks out of the mount by 1 mm, so you can grip it with your fingers to pull the case out, for example for charging.

The rails are at the same height as in the original case, so the case fits the existing mount.

---

## Reference

### Wiring

The wiring is the same as in the UV-Sight firmware README (firmware 5.8):

| Function | XIAO pin |
|---|---|
| UV LED, PWM through Q1 | D6 |
| LDR supply (HIGH only while measuring) | D2 |
| LDR measurement | A0 / D0 |
| Battery | BAT+ pad (via the VBAT wire), GND |

Full schematic: [docs/schematic.pdf](docs/schematic.pdf)

### J2: display / expansion connector

Eight holes behind the XIAO, directly below the LED pads. Pin 1 is the square pad.

```
 1  3V3          2  GND
 3  D7           4  D8  (SPI SCK)
 5  D9 (MISO)    6  D10 (SPI MOSI)
 7  5V           8  GND
```

- **SPI display:** fits directly. Use SCK = D8 and MOSI = D10; CS and DC on D7 and D9, for example.
- **I²C display:** the XIAO's default I²C pins D4 (SDA) and D5 (SCL) are on the other header row and are not on J2. Solder to the XIAO's header pins, or move I²C in the firmware.
- **5V** only exists while USB is plugged in. Power a display from 3V3.

### Opening the KiCad project

Open `kicad/uv-sight-carrier.kicad_pro` with KiCad 7 or newer. The project brings its own library for the XIAO footprint and the wire pads (`kicad/lib`); everything else comes from KiCad's standard libraries.

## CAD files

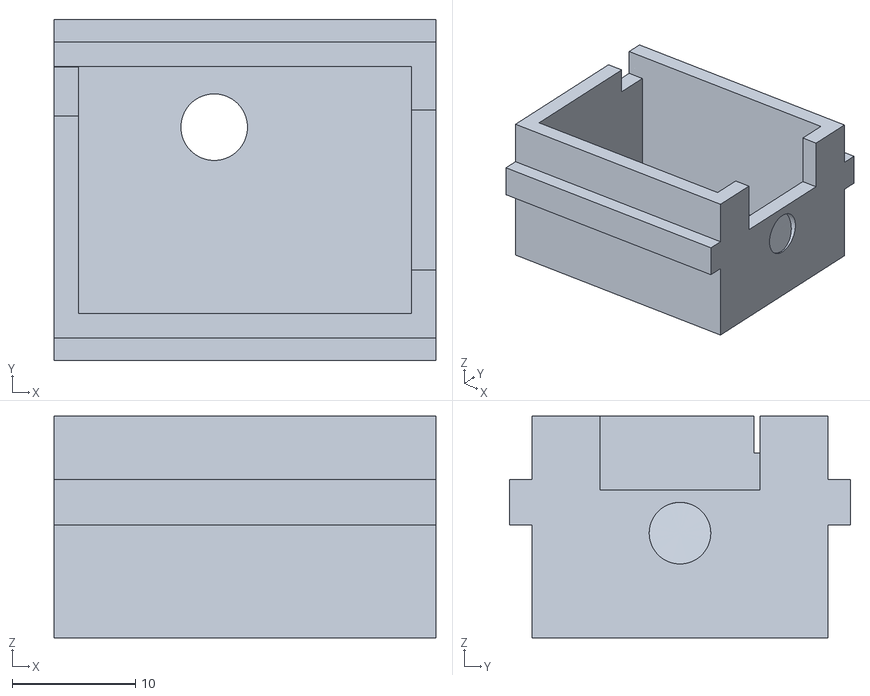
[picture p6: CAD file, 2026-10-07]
uv-sight-hardware/3d-print/case.stl
31.0 x 27.7 x 18.0

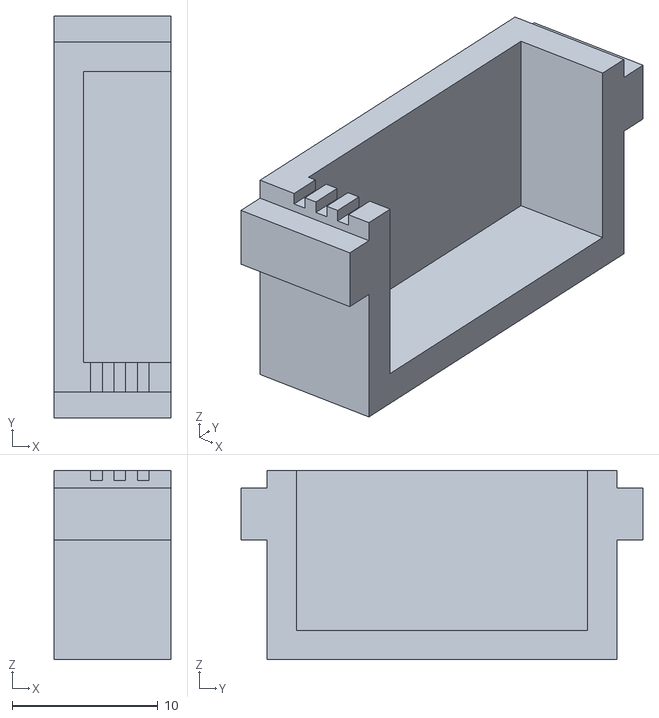
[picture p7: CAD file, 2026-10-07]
uv-sight-hardware/3d-print/rail-test/rail-test_minus-0.20mm.stl
8.00 x 27.6 x 13.0

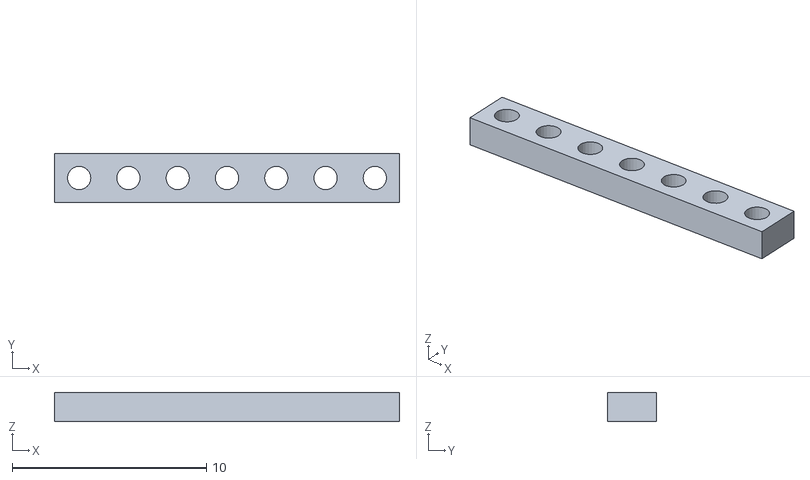
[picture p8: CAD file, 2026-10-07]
uv-sight-hardware/3d-print/header-spacer.stl
17.8 x 2.50 x 1.50

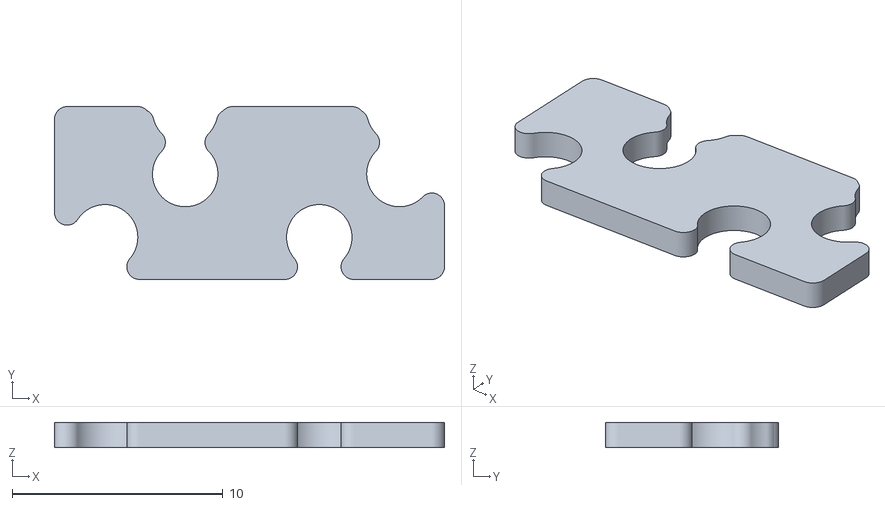
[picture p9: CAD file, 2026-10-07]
uv-sight-hardware/3d-print/shim.stl
18.5 x 8.20 x 1.20

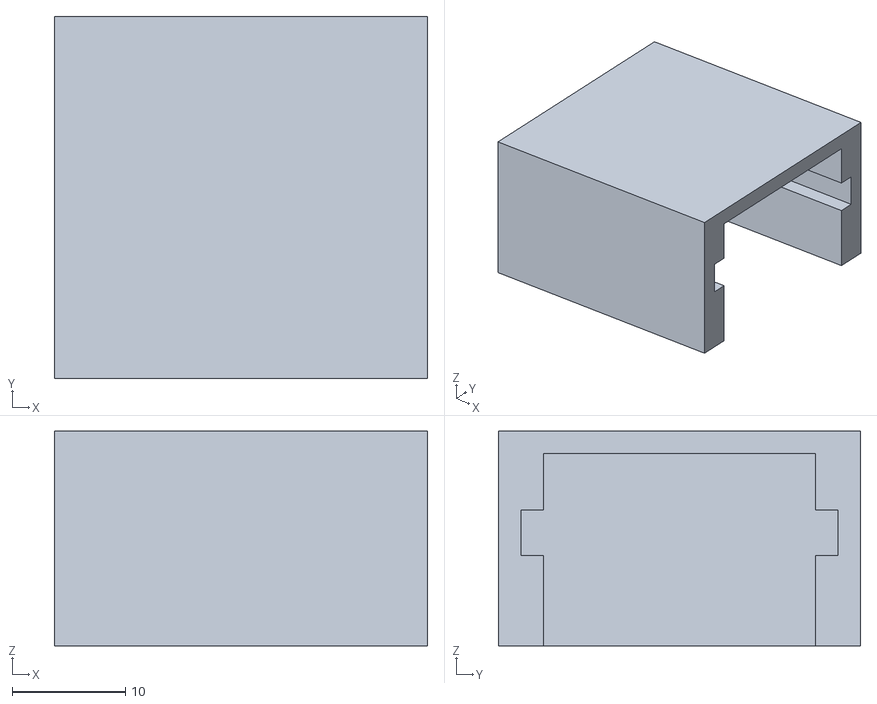
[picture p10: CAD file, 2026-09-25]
uv-sight-hardware/3d-print/bow-mount.stl
33.0 x 32.0 x 19.0

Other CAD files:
uv-sight-hardware/3d-print/rail-test/rail-test_minus-0.25mm.stl
uv-sight-hardware/3d-print/rail-test/rail-test_minus-0.10mm.stl
uv-sight-hardware/3d-print/rail-test/rail-test_minus-0.15mm.stl

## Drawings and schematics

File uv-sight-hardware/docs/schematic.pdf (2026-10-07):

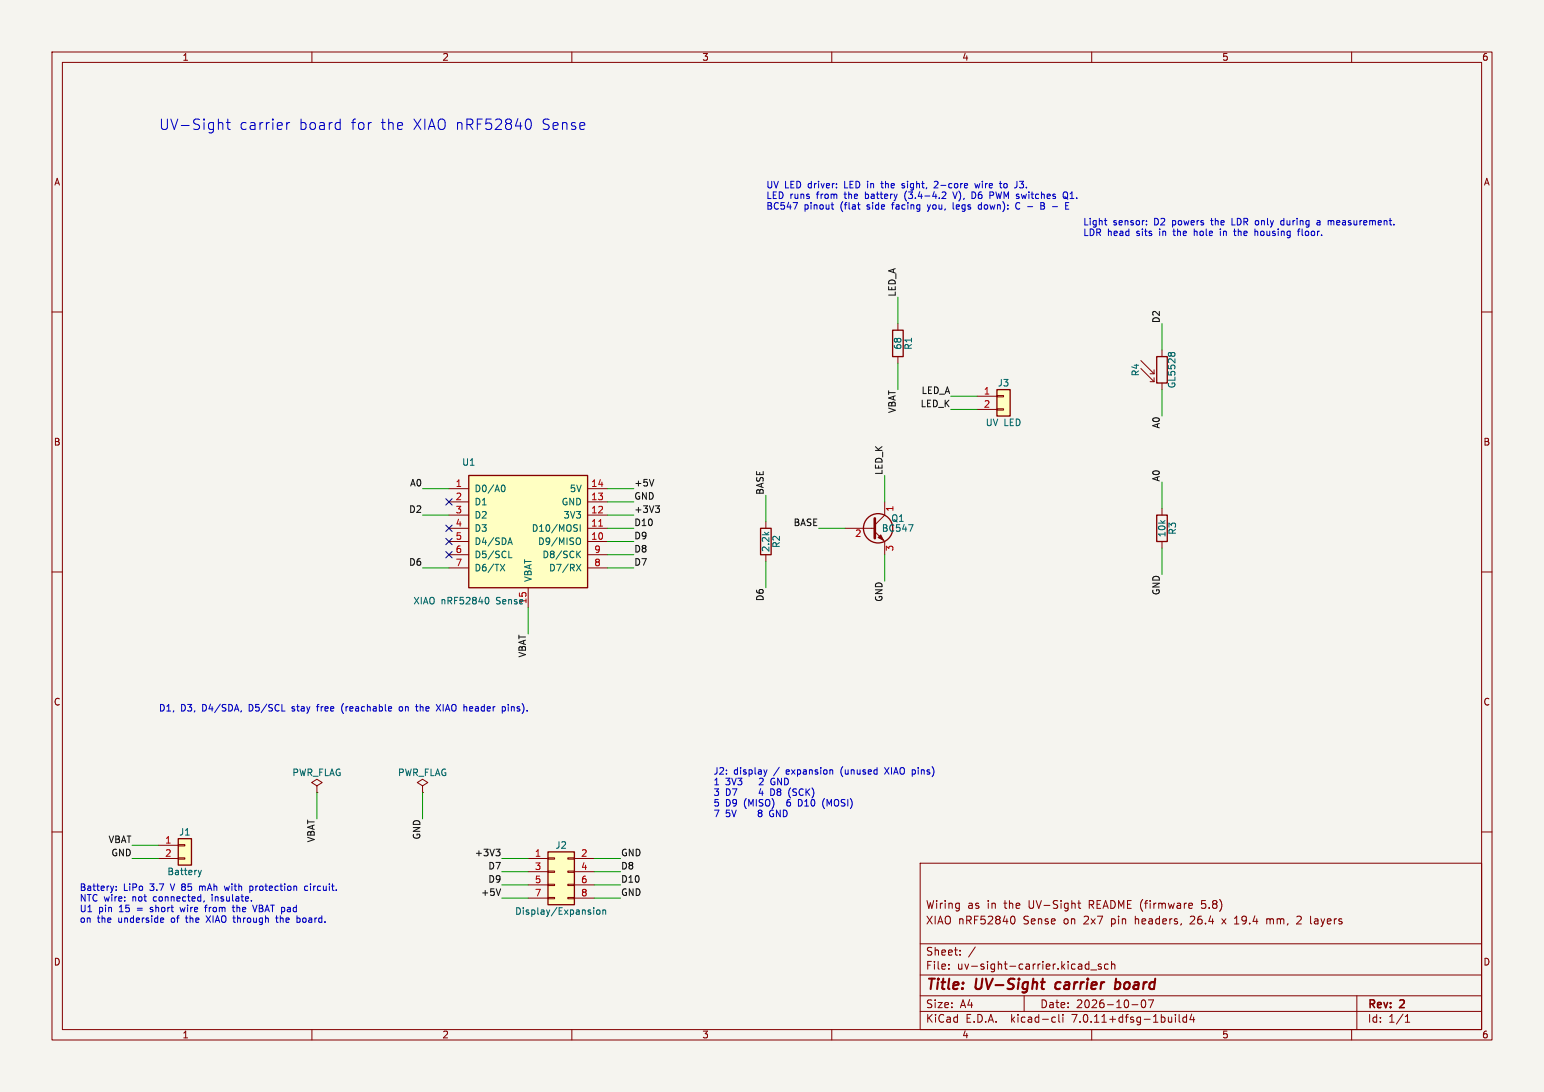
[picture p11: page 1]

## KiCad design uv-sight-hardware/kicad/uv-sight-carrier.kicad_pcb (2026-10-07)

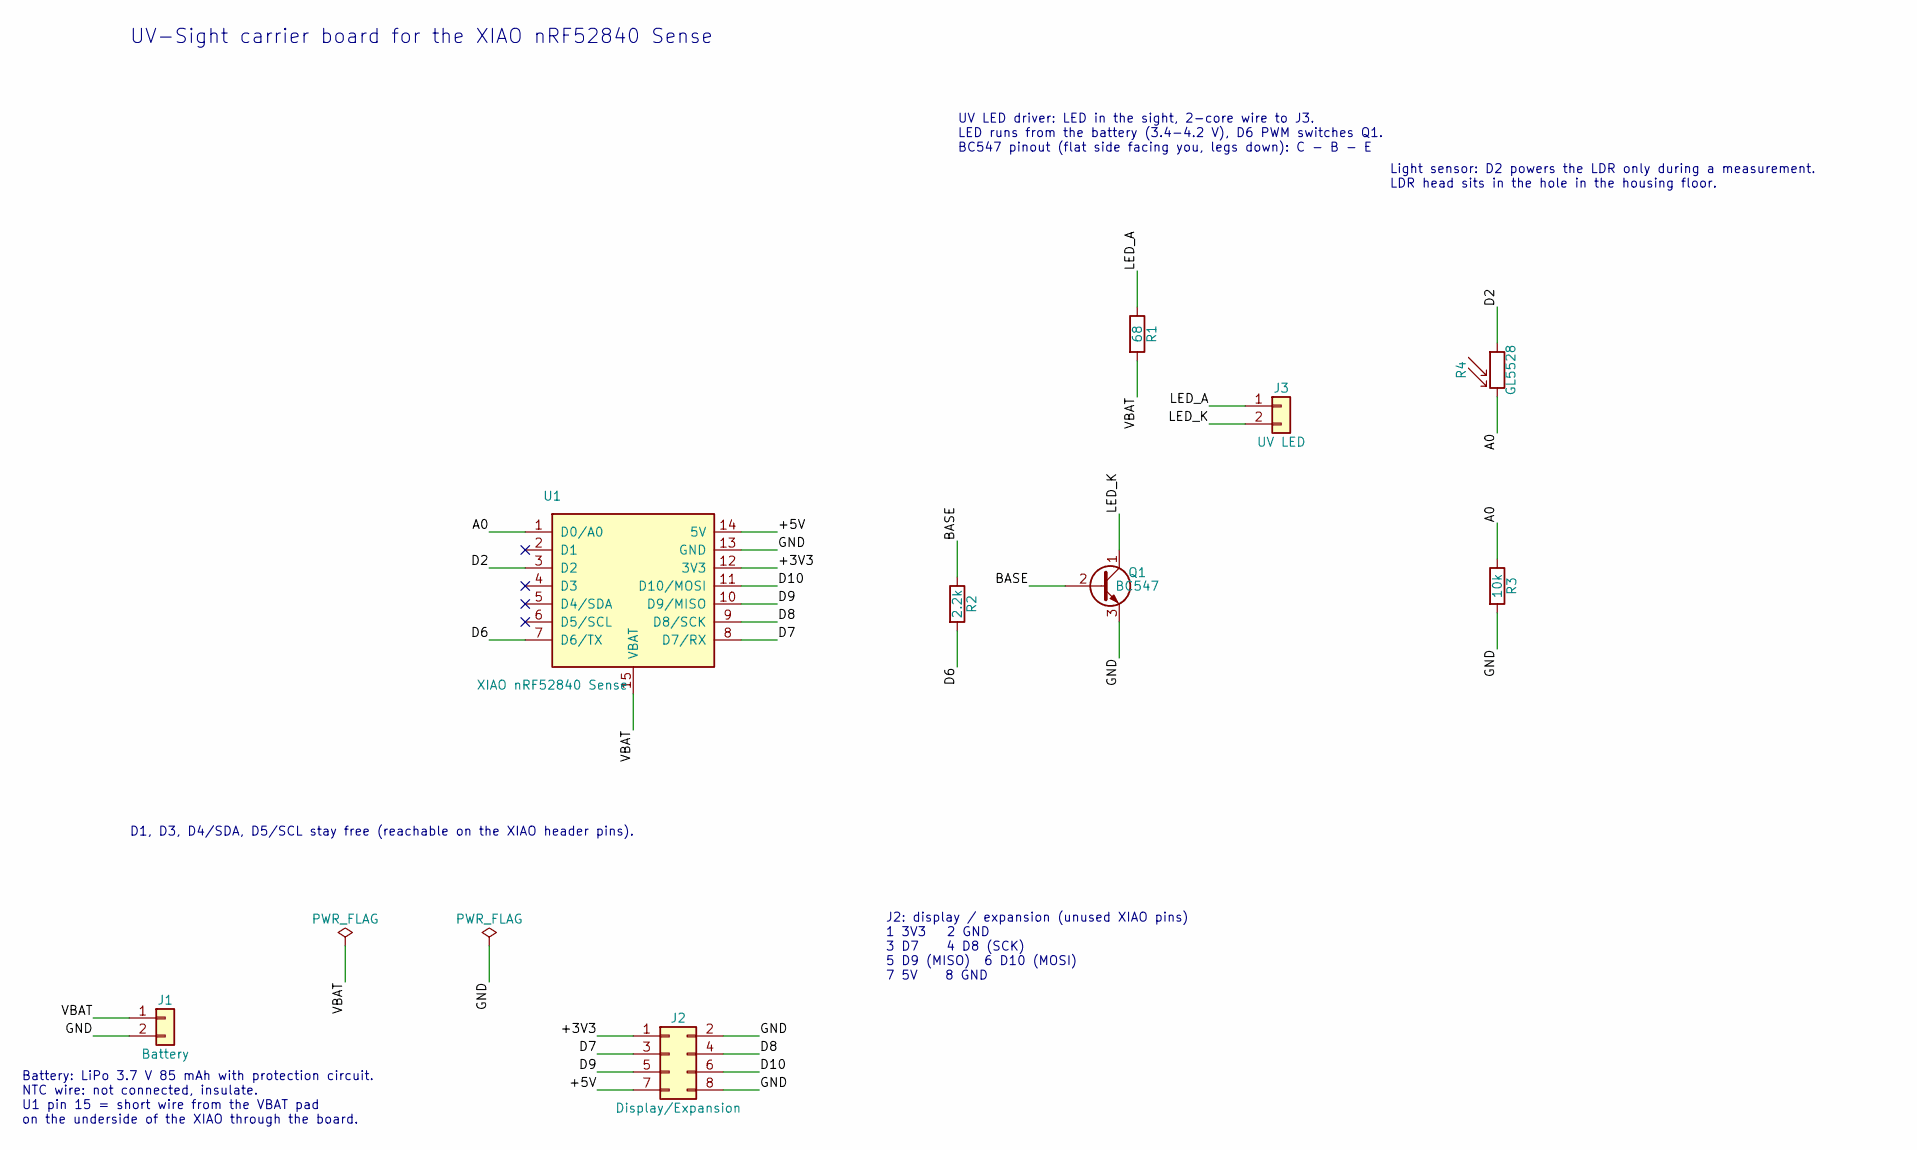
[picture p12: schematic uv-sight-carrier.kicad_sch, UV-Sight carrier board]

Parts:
J1: Battery; WirePad_1x02_P2.54mm
J2: Display/Expansion; PinHeader_2x04_P2.54mm_Vertical
J3: UV LED; WirePad_1x02_P2.54mm
Q1: BC547; TO-92_Inline
R1: 68; R_Axial_DIN0207_L6.3mm_D2.5mm_P10.16mm_Horizontal
R2: 2.2k; R_Axial_DIN0207_L6.3mm_D2.5mm_P10.16mm_Horizontal
R3: 10k; R_Axial_DIN0207_L6.3mm_D2.5mm_P10.16mm_Horizontal
R4: GL5528; R_LDR_5.1x4.3mm_P3.4mm_Vertical
U1: XIAO nRF52840 Sense; XIAO_nRF52840_Header_VBAT

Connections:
+3V3: J2.1, U1.12 (3V3)
+5V: J2.7, U1.14 (5V)
A0: R3.1, R4.2, U1.1 (D0/A0)
BASE: Q1.2 (B), R2.1
D2: R4.1, U1.3 (D2)
D6: R2.2, U1.7 (D6/TX)
D7: J2.3, U1.8 (D7/RX)
D8: J2.4, U1.9 (D8/SCK)
D9: J2.5, U1.10 (D9/MISO)
D10: J2.6, U1.11 (D10/MOSI)
GND: J1.2, J2.2, J2.8, Q1.3 (E), R3.2, U1.13 (GND)
LED_A: J3.1, R1.1
LED_K: J3.2, Q1.1 (C)
VBAT: J1.1, R1.2, U1.15 (VBAT)

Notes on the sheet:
UV-Sight carrier board for the XIAO nRF52840 Sense
UV LED driver: LED in the sight, 2-core wire to J3. LED runs from the battery (3.4-4.2 V), D6 PWM switches Q1. BC547 pinout (flat side facing you, legs down): C - B - E
Light sensor: D2 powers the LDR only during a measurement. LDR head sits in the hole in the housing floor.
Battery: LiPo 3.7 V 85 mAh with protection circuit. NTC wire: not connected, insulate. U1 pin 15 = short wire from the VBAT pad on the underside of the XIAO through the board.
J2: display / expansion (unused XIAO pins) 1 3V3 2 GND 3 D7 4 D8 (SCK) 5 D9 (MISO) 6 D10 (MOSI) 7 5V 8 GND
D1, D3, D4/SDA, D5/SCL stay free (reachable on the XIAO header pins).

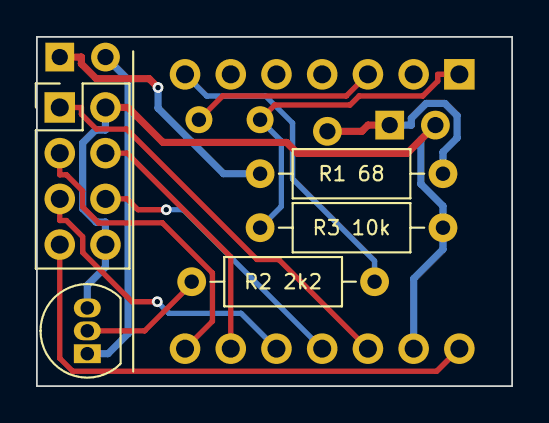
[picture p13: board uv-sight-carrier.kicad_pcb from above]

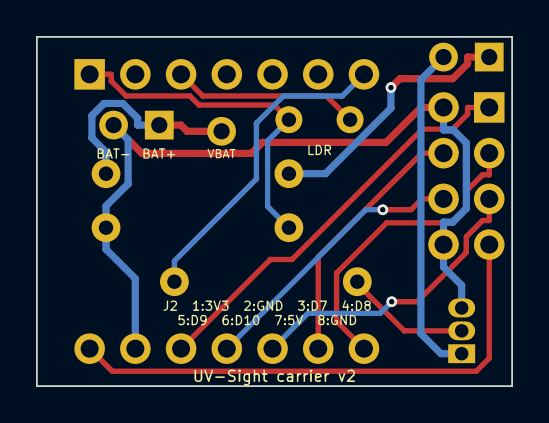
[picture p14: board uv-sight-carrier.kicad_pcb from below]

Board: 2 copper layers, 26.4 x 19.4 mm, 9 parts (2 on the bottom side), 14 nets.

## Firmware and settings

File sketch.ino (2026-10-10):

/*
  ============================================================================
  UV sight illumination + shot counter for compound bows
  Board: Seeed XIAO nRF52840 Sense
  ============================================================================

  Illumination
  ------------
  - Motion detection via the built-in IMU (accelerometer only).
  - If the bow lies still (timeout), everything is off: LED, light sensor, radio.
    The accelerometer drops to 12.5 Hz and the board sleeps until INT1 wakes it.
  - If the bow is moved and it is dark, the UV LED turns on.
  - Brightness is set in percent (perceptual scale).
    Mode "fixed": the LED switches on below dark_on with one brightness and
    off above dark_off.
    Mode "auto": the LED comes on at dark_off with bright_min and gets
    brighter as it gets darker, reaching "bright" at dark_on and staying
    there below. Getting brighter it dims the same way and goes off above
    dark_off.
  - Brightness is held steady over the battery discharge via PWM.
  - Battery level is shown via Bluetooth only ("status").
  - Below the cutoff voltage the LED turns off to protect the battery.
    The percentage display is tied to it: 0 % = cutoff voltage.

  Shot counter
  ------------
  - Shot = impact above the tap threshold (IMU tap detection). The IMU
    signals a tap on its INT1 line (P0.11), which triggers a hardware
    interrupt, so no shot is missed between two loop passes. While the bow
    rests the same line carries the motion wake-up, so the board sleeps
    until the bow is picked up instead of polling the IMU.
    After a shot there is a lockout ("lockout", default 1.5 s): further
    impacts are ignored (vibration) and the tilt indicator pauses.
  - Shot strength: in shot mode the IMU fills its FIFO at 416 Hz (+-16 g).
    After a shot the peak of the total acceleration is read from it and
    reported in g. It is a comparison value for setting tap_ths, not an
    exact physical peak (416 Hz sampling misses the sharpest part).
  - A training session starts with the first shot or with "shots start".
  - A session ends after "session_end" minutes (default 60) without a
    detected shot, or with "shots stop".
    Normal movement does not count.
  - Scores: 0-10 or "x" (inner ten: 10 points, counted separately).
  - A session consists of ends. Each "score" line closes an end and is
    compared with the shots counted since the last entry. On mismatch the
    device asks: yes = accept the entered values (and their arrow count),
    no = discard the input, the end stays open.
  - "score skip" closes an end without scores (invalid, arrow count from
    the sensor, all arrows 0 points, not included in the overall average).
  - Last end without entry at session end: 1 shot is ignored (setting the
    bow down), more than 1 shot = invalid end.
  - Sessions are stored on the external 2 MB QSPI flash as 64-byte records
    with CRC (about 32,000 sessions; the oldest are overwritten when full):
    date (if the app set the clock), ends, shots, scored arrows, average,
    X, invalid ends/arrows, duration. A log of firmware 1.2 - 2.1 in the
    internal flash is taken over automatically on the first start.

  Tilt indicator (cant)
  ---------------------
  - If the bow is canted sideways, the LED blinks at reduced brightness,
    regardless of bright/dark. Style "normal": the more tilted, the faster.
    Style "inverted": the closer to level, the faster.
        bright + level = off        dark + level = on
        bright + tilted = blinks    dark + tilted = blinks
  - Only sideways cant counts, not aiming up or down.
  - Three modes: "level off", "level auto" (only during a running session,
    needs "shots on") and "level on" (always while the bow is active).
  - One-time calibration in two steps ("level cal", "level cal2").

  Bluetooth (Android app "Serial Bluetooth Terminal")
  ---------------------------------------------------
  - The board is only visible while it is active (bow moved).
  - A connection does NOT keep the board active: after the timeout without
    movement it is disconnected. Move the bow now and then while configuring.
  - Command "help" lists all commands.

  App mode (JSON protocol)
  ------------------------
  - "app on" switches ALL output to one JSON object per line, "app off"
    back to human-readable text. Disconnecting also switches back.
  - Commands stay the same text commands in both modes.
  - Stored sessions carry an "id" (running number) and the log an "epoch"
    (random, new whenever the log starts empty), so the app can archive
    them without duplicates. "ago" = minutes since saving (null after reboot).
  - "log put" writes a session from a backup into the log (skipped if its
    epoch + id are already stored). The app uses it to restore the sight.
  - Every line has a type field "t": hello, status, cfgStart/cfgItem/cfgEnd,
    session, shot, end,
    confirm, discarded, sessionEnd, logStart/slot/logEnd, level, cal,
    event, ack, err, msg. See the protocol description in the manual.

  Wiring
  ------
  UV LED via NPN transistor (BC547):
    BAT+ --[68 Ohm]-- UV LED anode(+) -- UV LED cathode(-) -- collector
    D6   --[2.2 kOhm]-- base
    GND  -- emitter

  Light sensor:
    D2 --[LDR]--+--[10 kOhm]-- GND
                |
                A0

  Battery: directly on the BAT+ / BAT- pads (voltage is measured internally).
  Charge current: fixed 50 mA (suits the 85 mAh battery, set in code).
  Charge status: P0.17 (board charge LED, LOW = charging) + USB detection.

  Arduino IDE setup
  -----------------
  1. Boards manager URL:
       https://files.seeedstudio.com/arduino/package_seeeduino_boards_index.json
  2. Install board package "Seeed nRF52 Boards" (NOT "mbed-enabled").
  3. Board: "Seeed XIAO nRF52840 Sense"
  4. Library "Seeed Arduino LSM6DS3" via the library manager.
     (Bluefruit and LittleFS are included in the board package.)
  ============================================================================
*/

#include <Arduino.h>
#include <Wire.h>
#include <LSM6DS3.h>
#include <bluefruit.h>
#include <nrf_nvic.h>   // sd_nvic_SystemReset
#include <nrfx_qspi.h>  // external 2 MB flash for the session log
#include <Adafruit_LittleFS.h>
#include <InternalFileSystem.h>
#if __has_include(<nrf52_erratas.h>)
  #include <nrf52_erratas.h>   // Nordic MDK: which errata apply to the chip revision at hand
  #define HAVE_NRF52_ERRATAS 1
#endif

using namespace Adafruit_LittleFS_Namespace;

#if !defined(PIN_VBAT) || !defined(VBAT_ENABLE)
  #error "Wrong board: select 'Seeed XIAO nRF52840 Sense' from 'Seeed nRF52 Boards' (not mbed)."
#endif

#if !defined(PIN_QSPI_SCK) || !defined(PIN_QSPI_CS) || !defined(PIN_QSPI_IO0) || \
    !defined(PIN_QSPI_IO1) || !defined(PIN_QSPI_IO2) || !defined(PIN_QSPI_IO3)
  #error "Board package without QSPI pin definitions: the session log needs the external flash."
#endif

#ifndef PIN_LSM6DS3TR_C_INT1
  #warning "PIN_LSM6DS3TR_C_INT1 not defined: shot detection falls back to polling only."
#endif

// ============================================================================
// FIXED VALUES
// ============================================================================

// Pins (Arduino pin n = XIAO Dn)
const uint8_t PIN_UV      = 6;    // D6 -> 2.2k -> base of BC547
// UV LED stage present? 0 = no (hunting bow without a sight: no LED, no light sensor), 1 = yes,
// 2 = find out at boot: with the BC547 and its base resistor fitted, a pin charged HIGH and then
// released falls to the base-emitter voltage within microseconds; without them it stays HIGH.
// Without the LED stage all light settings default to off and the app hides them.
#ifndef UV_HAS_LED
#define UV_HAS_LED 2
#endif
bool ledPresent = true;
const uint8_t PIN_LDR_PWR = 2;    // D2 powers the LDR only during a measurement
const uint8_t PIN_LDR     = A0;   // midpoint LDR / 10k

// Timing
const uint32_t IDLE_POLL_MS       = 500;   // loop interval while idle (fallback without INT1)
const uint32_t IDLE_WAKE_MAX_MS   = 5000;  // idle: longest sleep between housekeeping passes
const uint32_t ACTIVE_POLL_MS     = 250;   // loop interval while active
const uint32_t SENSOR_INTERVAL_MS = 2000;  // check light + battery every 2 s
const uint32_t IMU_SETTLE_MS      = 1000;  // ignore motion after a mode change
const uint32_t LEVEL_LOOP_MS      = 30;    // loop interval while the tilt indicator runs
const uint32_t AWAKE_MAX_S        = 900;   // longest hold the app can ask for ("awake <s>")
const uint32_t AWAKE_PUT_MS       = 60000; // every "log put" keeps the sight awake this long

// Circuit
const float R_LED_OHM      = 68.0;
const float V_CE_SAT       = 0.1;
const float VBAT_DIVIDER   = 1510.0 / 510.0;   // internal divider 1M / 510k
const float ADC_MV_PER_LSB = 3600.0 / 4096.0;  // 12 bit, 3.6 V reference

// Battery protection
const float VBAT_RECOVER_OFFSET = 0.25;

// Brightness: percent -> LED current on a perceptual curve
const float    BRIGHT_MAX_MA   = 15.0;  // current at 100 %
const float    BRIGHT_GAMMA    = 2.2;   // 50 % looks about half as bright
const uint8_t  PWM_BITS        = 12;    // fine steps at low brightness
const uint16_t PWM_MAX         = (1u << PWM_BITS) - 1;

// Tilt indicator (adjustable here in the sketch)
const float    TILT_HYST_FRAC    = 0.3;   // hysteresis at the tolerance edge, share of level_tol
const float    CAL_MIN_ANGLE_DEG = 15.0;  // minimum angle between calibration steps
const uint32_t CAL_COUNTDOWN_MS  = 3000;  // wait time before a calibration measurement

// Shot counter
const uint8_t  MAX_SCORES_LINE = 40;

// Firmware / protocol
const char*    FW_VERSION        = "6.3";
const uint8_t  PROTO_VERSION     = 21;

// Bluetooth
const char*    BLE_NAME          = "UV-Sight";
const char*    NAME_FILE         = "/sightname.txt";   // the name the owner gave this sight ("name <text>")
char           sightName[20]     = "";                 // shown in the app and appended to the BLE name
const uint16_t ADV_FAST_INTERVAL = 160;   // 100 ms (unit 0.625 ms), first 10 s
const uint16_t ADV_SLOW_INTERVAL = 1636;  // ~1 s afterwards
const uint16_t ADV_FAST_TIMEOUT  = 10;    // s
const uint16_t CONN_INT_MIN      = 160;   // 200 ms (unit 1.25 ms)
const uint16_t CONN_INT_MAX      = 320;   // 400 ms
const uint16_t BLE_MTU           = 247;   // max. packet size (default would be 23)
const uint8_t  BLE_SEND_RETRIES  = 50;    // retries per packet when the queue is full
const uint16_t BLE_RETRY_MS      = 20;    // wait between retries

// Power
// nRF52840 erratum 89: a TWIM (I2C) that stays enabled while GPIOTE is used
// draws a static 400 uA. Per the Nordic errata this only affects the revision
// Engineering A; every production revision is free of it. The workaround
// (switch the bus off between loop passes and toggle its power domain) is
// therefore only applied when the chip says it needs it.
//   0 = never, 1 = automatic (checked at start with the MDK, off if the MDK
//   header is missing), 2 = always
#define TWIM_ANOMALY_89   1

// ============================================================================
// SETTINGS (changeable via Bluetooth, stored in flash with "save")
// ============================================================================
struct Config {
  uint32_t magic;
  uint16_t darkOn;       // LDR value: below = dark
  uint16_t darkOff;      // LDR value: above = bright again
  uint8_t  darkConfirm;  // consecutive readings needed to switch
  uint8_t  wakeThs;      // motion threshold, 1 LSB = 125 mg (1..63)
  uint8_t  tapThs;       // shot threshold,   1 LSB = 250 mg (1..62)
  float    targetMa;     // legacy (firmware < 1.8), only read for migration
  float    vf;           // forward voltage of the UV LED
  float    cutoff;       // battery cutoff voltage
  uint32_t timeoutS;     // s without movement until idle
  uint32_t reportS;      // s between status reports (when connected), 0 = off
  float    tiltMa;       // legacy (firmware < 1.8), only read for migration
  float    levelTol;     // tilt tolerance in degrees
  uint32_t lockoutMs;    // after a shot: ignore impacts + pause tilt indicator, ms
  int8_t   txPower;      // Bluetooth transmit power in dBm
  uint8_t  brightMode;   // 0 = fixed, 1 = auto (follows the light sensor)
  float    brightMax;    // % : fixed brightness, or brightness at dark_on and darker (auto)
  float    brightMin;    // % : auto: brightness at dark_off, where the light starts
  float    tiltOffset;   // %-points below brightMax while tilt-blinking
  uint16_t sessionEndMin; // minutes without a shot until the session ends
  uint16_t tiltSmoothMs;  // smoothing of the cant reading against hand tremor
  float    tiltFullDeg;   // cant at which the blink rate reaches its end value
  float    blinkMinHz;    // blink rate just outside the tolerance (normal style)
  float    blinkMaxHz;    // blink rate from tiltFullDeg on (normal style)
  float    fadeS;         // auto brightness: time to follow a change, s (0 = instant)
  uint16_t batMah;        // battery capacity, for the runtime estimate
                         // (new fields are appended at the end so older stored
                         //  settings stay valid and get the default for them)
};

// Increase this number when the structure layout changes,
// old stored values are then discarded.
const uint32_t CFG_MAGIC = 0x55560003;
const char*    CFG_FILE  = "/uvcfg.bin";

const Config DEFAULTS = {
  CFG_MAGIC,
  900,     // darkOn
  1200,    // darkOff
  2,       // darkConfirm
  1,       // wakeThs (125 mg)
  20,      // tapThs (5 g)
  5.0f,    // targetMa
  3.0f,    // vf (measured 2.873 V at ~1 mA + margin)
  3.40f,   // cutoff
  300,     // timeoutS (5 min)
  10,      // reportS
  1.0f,    // tiltMa
  1.0f,    // levelTol (degrees)
  1500,    // lockoutMs
  0,       // txPower (dBm, about 10 m)
  0,       // brightMode (fixed)
  61.0f,   // brightMax (= 5 mA, the former default)
  25.0f,   // brightMin
  32.0f,   // tiltOffset (tilt blink at about 1 mA, the former default)
  60,      // sessionEndMin
  400,     // tiltSmoothMs
  10.0f,   // tiltFullDeg
  1.0f,    // blinkMinHz
  8.0f,    // blinkMaxHz
  5.0f,    // fadeS
  85       // batMah
};

Config cfg = DEFAULTS;

// One table for all settings: used by "set", "get" and the JSON cfg list
enum SType : uint8_t { S_U8, S_I8, S_U16, S_U32, S_F };
struct SettingDef {
  const char* key;
  SType       type;
  size_t      off;
  float       mn, mx;
  uint8_t     dec;      // decimals for display
  bool        zeroOk;   // 0 allowed outside the range (= off)
  const char* unit;
  const char* desc;
};
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
void loop() {
  uint32_t   now       = millis();
  const bool connected = Bluefruit.connected();
  imuBus(true);

  if (!connected) { liveMode = false; welcomed = false; appMode = false; }
  // A command cut off by a lost connection must not be glued to the first one
  // of the next connection: start every connection with an empty line buffer
  static bool wasConnected = false;
  if (connected != wasConnected) { rxBuf = ""; wasConnected = connected; }

  // Only movement keeps the board active (a connection does not)
  if (imuMotionSinceLastCheck()) lastMotionMs = now;

  // Shot: the INT1 edge gives the exact time; the latched TAP_SRC confirms it
  // (in shot mode INT1 only carries the tap) and re-arms the line
  bool     shot   = false;
  uint32_t shotAt = now;
  bool     edge   = false;
  if (int1Flag) {
    noInterrupts();
    shotAt   = int1Ms;
    int1Flag = false;
    interrupts();
    edge = true;
  }
  if (imuTapSinceLastCheck()) shot = true;
  if (!edge) shotAt = now;                   // tap found by polling only
  if (imuFast && !shot && fifoHasGyro != gyroWanted()) { imuFast = false; imuSetFast(true); }   // calibration or "shot on|off" changed the layout
  if (shot) {
    lastMotionMs = now;
    if (shotAllowed(shotAt)) {
      bool clip = false; ShotKin kin;
      const float g = readShotFifo(&clip, &kin);   // strength and bow rotation from the FIFO
      registerShot(shotAt, g, clip, kin);
    }
  } else if (imuFast && fifoWords() > FIFO_KEEP_WORDS) {
    fifoRestart();                            // keep only the recent data
  }

  const bool active = (now - lastMotionMs) < cfg.timeoutS * 1000UL;

  // Stay reachable without movement while charging over USB or while the app
  // holds the sight awake (e.g. "Copy to sight"). Only Bluetooth and readings:
  // LED, shot detection and cant indicator still need movement.
  const bool usb  = usbPresent();
  const bool held = (int32_t)(awakeUntil - now) > 0;
  awakeReason = active ? "" : (usb ? "usb" : (held ? "app" : ""));
  const bool reachable = active || usb || held;

  // Battery history: time per state, and points at state changes
  bhTick(now, reachable);
  if (usb != bhPrevUsb) {
    if (usb) {                                   // voltage from just before the charger took over
      plugMs = now;
      plugSoc = (now - unloadedMs) < 120000 ? rawPercent(unloadedMv / 1000.0f) : -1;
      bhPoint(BP_USB_IN, unloadedMv, true);
      bhPending = 0;
    } else {
      plugSoc = -1;
      ledOffMs = now;                             // let the charged battery relax first
      bhPointUnloaded(BP_USB_OUT, true);
    }
    bhPrevUsb = usb;
  }
  if (active != bhPrevActive) {
    if (!active) {                               // falling asleep
      bhIdlePointMs = now;
      if (!usb) bhPointUnloaded(BP_IDLE, false);
    } else if (bhIdlePointMs && (now - bhIdlePointMs) >= BH_IDLE_MIN_MS && !usb) {
      bhPoint(BP_WAKE, (uint16_t)(readVbat() * 1000), true);   // LED is still off here
    }
    bhPrevActive = active;
  }
  bhService(now, usb);

  // Shot detection only if the counter is on and the bow is in use; at rest the
  // accelerometer runs at its slowest rate
  imuSetFast(active && shotState.shotsOn);
  imuSetIdleOdr(!active);

  // End the session automatically after session_end minutes without a shot
  if (sessionActive && (now - sessionLastShotMs) >= cfg.sessionEndMin * 60000UL) {
    finishSession(false);
  }

  bleUpdate(reachable);
  readCommands();
  now = millis();

  // Greeting as soon as the app is ready
  if (connected && bleuart.notifyEnabled() && !welcomed) {
    welcomed = true;
    out("UV-Sight connected. 'help' lists all commands.");
    if (!imuOk) out("Note: IMU not found, motion detection off.");
    sendStatus();
    if (sessionActive) out(sessionLine());
    if (lvl.on && !lvl.calibrated) out("Note: tilt indicator not calibrated ('level cal').");
    lastReportMs = now;
  }

  // ---- Idle: bow lies still ----
  if (!active) {
    if (ledMaNow > 0) { ledMaNow = 0; ledOffMs = now; }
    uvOff();
    ledState = LS_OFF;
    tiltReset();
    wasInactive = true;
    darkCount = brightCount = 0;
    if (reachable) {
      // Kept awake: fresh readings for the app, LED stays off
      if ((now - lastSensorMs) >= SENSOR_INTERVAL_MS) {
        lastSensorMs = now;
        evaluate();
        wasInactive = true;            // evaluate() cleared it; the bow is still at rest
        if (liveMode) { sendStatus(); lastReportMs = now; }
      }
      if (connected && !liveMode && cfg.reportS > 0 && (now - lastReportMs) >= cfg.reportS * 1000UL) {
        sendStatus();
        lastReportMs = now;
      }
      imuBus(false);
      delay(ACTIVE_POLL_MS);
      return;
    }
    imuBus(false);
    idleSleep();
    return;
  }

  // ---- Active ----
  if (wasInactive || (now - lastSensorMs) >= SENSOR_INTERVAL_MS) {
    lastSensorMs = now;
    evaluate();
    if (liveMode) { sendStatus(); lastReportMs = now; }
  }

  const bool lvlOn = levelActive();
  const bool angOn = angleActive();
  if (lvlOn || angOn) updateOrientation(lvlOn, angOn);
  if (!angOn && !lvlOn) pitchFill = 0;        // no stale readings into the next session
  rangeWarnUpdate(millis());
  updateLed(millis());

  // Periodic status report, only when connected
  if (connected && !liveMode && cfg.reportS > 0 && (now - lastReportMs) >= cfg.reportS * 1000UL) {
    sendStatus();
    lastReportMs = now;
  }

  imuBus(false);
  delay((lvlOn || angOn) ? LEVEL_LOOP_MS : ACTIVE_POLL_MS);
}

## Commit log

2026-09-30 Fix sync races and lost log lines, cut idle and I2C current
    Firmware 5.7, protocol 15, app 5.10.
    Fixes
    - Read-only commands (status, log, level, sync commands of the app) no
    longer withdraw an open score question; the app also waits with its
    automatic log sync while a question is open. Saving an end right after
    a reconnect no longer loses the "save anyway" answer.
    - A session the flash could not store is reported with seq 0, and the
    app only moves its fetch marker for stored sessions.
    - logEnd carries the number of records sent; the app asks again when a
    line was lost instead of moving its marker past the gap.
    - FIFO word count read with the full 12-bit mask.
    - status reports "war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
    [sketch.ino]
2026-09-30 Apply the erratum 89 workaround only on affected chip revisions
    Per the Nordic MDK (nrf52_erratas.h), nRF52840 erratum 89 only affects
    the Engineering A revision. The firmware now asks nrf52_errata_89() at
    start and enables the I2C power-cycling only there. TWIM_ANOMALY_89:
    0 = never, 1 = automatic (default; off when the MDK header is missing),
    2 = always. "hello" reports twim89, "bat" prints the decision.
    Claude-Session: https://claude.ai/code/session_014JG6jdHEc41tKn1ibqJNYb
    [sketch.ino]
2026-09-30 Report changes of the aiming-range signal as an event (protocol 16)
    The app can mirror the LED's range signal, e.g. with the phone's
    vibration motor: {"t":"event","e":"range","warn":"low"|"high"|"","ok":b}
    goes out whenever the warning, its direction or "aim fits" changes.
    Firmware 5.8, web app 5.11.
    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
    [sketch.ino]
2026-10-04 Sight identity: chip id and owner-given name (protocol 17)
    hello now carries "id" (nRF52 device id) and "sname", so an app can tell
    two sights apart. New command "name <text>" (max. 16 chars, "name -"
    removes it) stores the name in /sightname.txt and appends it to the
    advertised Bluetooth name. Firmware 5.9, web app 5.12 shows the name.
    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
2026-10-04 Shot matching: bow rotation at release, predictions and learning per setup (protocol 18)
    In shot mode the gyro runs with the accelerometer in the IMU FIFO; after
    the impact the sight integrates the bow's rotation over the 30 ms before
    it (yaw about the vertical, roll about the arrow axis, peak rate). Per
    shot it predicts the arrow's position relative to the end's mean: height
    from the aiming angle and distance, sideways from the rotation once
    learned. The app confirms pairs ("shot teach"), and the setup's model
    (ridge least squares with residual spreads, /shotmodel.bin) improves.
    New: "shot list [m]", "shot teach", "shot model", "shot reset", "shot on|off";
    the end message carries the shots.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
    [sketch.ino]
2026-10-04 Per-shot timing, hold, sinking and aim trace (protocol 19)
    Each shot now also records its time, the spread of the aiming angle while
    holding, how long the aim stayed steady, whether it sank in the last
    150..400 ms, and the angle/cant history of the 1.9 s before the release.
    "shot list" and the end message carry t/hold/holdMs/drop; "shot trace
    [last] <i>" returns the trace of one shot. Firmware 6.1, web app 5.14.
    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
2026-10-04 Sights without the UV LED stage (protocol 20)
    UV_HAS_LED build parameter (default 2: detect at boot by charging the LED
    pin and letting it float; the BC547's base-emitter junction pulls it
    low). Without the stage: light settings default to off, the light sensor
    is not read, mode/level signal/range signal "on" are refused, and hello
    carries "led":false so the apps hide every light option. Firmware 6.2,
    web app 5.15 hides LED, light sensor, blinking and distance warning rows.
    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
2026-10-10 Shot list as single lines (protocol 21)
    The end message had grown past a kilobyte with the shots array, long
    enough to be cut on the way through Bluetooth. The shots now go out as
    short lines like the other lists: shotsStart, one shotItem per shot,
    shotsEnd; after every closed end and on "shot list". The end message is
    short again. Firmware 6.3, web app 5.16.
    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
    [sketch.ino]
2026-10-21 Send the aim trace in parts (protocol 22)
    A whole trace is over 1 kB in one line, which the BLE link does not reliably carry (the same
    reason the shot list went to single lines). The trace now goes out as lines of 8 samples with the
    index of the first and the total count; the app joins them.
    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
2026-10-24 Shared sight: owners, password, trainers, two links, board data (protocol 23)
    An app may greet with app on <id> <name>; sessions started while it is connected carry that archer
    (reserved bytes of the record, owner fields in slot and session). The sight accepts two Bluetooth
    links: the archer's is primary and gets every live line, a second link only reads and ends sessions.
    group set locks the sight with a salted SHA-256 password hash, auth unlocks a link; whoever sets the
    first password is the first trainer, further trainers are requested and approved, the last one is
    removed over USB only. Users see their own and ownerless sessions, trainers everything. Every
    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
2026-10-25 Anchored and Nocked: new names, firmware 7.3, web app 5.20, new icons
    - The sight is called Anchored and advertises under that name (it was
    "UV-Sight"; the apps find both). Firmware 7.3, protocol unchanged (24).
    - The web app is called Nocked: title, home-screen name, install texts,
    export file names (nocked-backup, nocked-ends); the backup format id
    stays. It connects to sights of either name.
    - New icons from the Nocked logo (plain with transparent corners, and a
    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
2026-10-25 Factory reset (firmware 7.4): "factory", then "factory confirm"
    Erases every file in internal flash (settings, calibration, setups,
    shot model and counter, group with password and trainers, badges,
    name, battery history) and every used sector of the session log, then
    restarts: the sight is as freshly flashed, only the chip id stays.
    "factory" arms it for 30 s, "factory confirm" does it. On a shared
    sight trainers only, like "defaults" and "log clear".
    Web app 5.21: "Factory reset" next to "Restore defaults", with the
    copy-back question afterwards as after deleting the sessions.
    Claude-Session: https://claude.ai/code/session_014JG6jdH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
2026-10-25 Factory reset gives the sight a new id (firmware 7.5)
    The reset draws a random 64-bit id, keeps it in /sightid.bin and
    reports it in its acknowledgement; from the next boot the sight
    introduces itself with it, in the hello and in the advertisement. To
    the apps it is a new sight, so nothing they hold about the old one
    flows back. Without the file the chip's own id is used, so existing
    sights keep theirs across the update.
    Web app 5.22: no copy-back question after the reset.
    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
2026-10-26 LED auto: on only when it is dark and a session is running (firmware 7.6)
    A session starts with the first registered shot or with "shots start",
    so the pin stays dark until then; the cant blinking and the distance
    warning are unchanged. Web app 5.23 and README describe it.
    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
